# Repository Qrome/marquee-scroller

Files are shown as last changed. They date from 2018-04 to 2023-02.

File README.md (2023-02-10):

# Marquee Scroller (Clock, Weather, News, and More)

## NOTICE
The latest version of Marquee Scroller 3.01 works with **ESP8266 Core 3.0.2** -- if you are upgrading from Marquee Scroller 2.X version this may require you to enter in all your API Keys and settings.  Always meake sure you have coppied all your API keys somewhere before updating.  The ESP8266 Core 3.0.2 uses the newer FS (file system) that may require a fresh start on the configuration.
Make sure you update to the latest version of WifiManager library (link below).
* Removed Bitcoin features in 3.0

## Features include:
* Accurate Clock refresh off Internet Time Servers
* Local Weather and conditions (refreshed every 10 - 30 minutes)
* News Headlines from all the major sources
* Configured through Web Interface
* Display 3D print progress from your OctoPrint Server
* Option to display Pi-hole status and graph (each pixel accross is 10 minutes)
* Basic Authorization around Configuration web interface
* Support for OTA (loading firmware over WiFi)
* Update firmware through web interface
* Configurable scroll speed
* Configurable scrolling frequency
* Configurable number of LED panels
* Options of different types of Clock Displays (display seconds or temperature) -- only on 8 or more display panels
* Video: https://youtu.be/DsThufRpoiQ
* Build Video by Chris Riley: https://youtu.be/KqBiqJT9_lE

## Required Parts:
* Wemos D1 Mini: https://amzn.to/3tMl81U
* Dot Matrix Module: https://amzn.to/2HtnQlD  

Note: Using the links provided here help to support these types of projects. Thank you for the support.  

## Wiring for the Wemos D1 Mini to the Dot Matrix Display
CLK -> D5 (SCK)  
CS  -> D6  
DIN -> D7 (MOSI)  
VCC -> 5V+  
GND -> GND-  

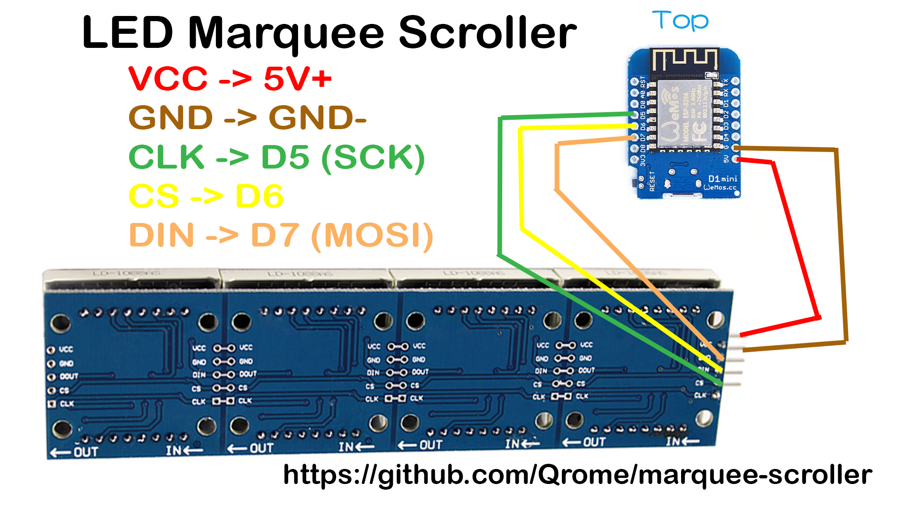
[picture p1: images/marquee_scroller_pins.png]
Marquee Scroller Wiring
  

## 3D Printed Case by David Payne:  
Original Single Panel version: https://www.thingiverse.com/thing:2867294  
Double Wide LED version: https://www.thingiverse.com/thing:2989552  

## Upgrading from version 2.5 or Higher
In version 2.6 and higher, the binary files that can be uploaded to your marque scrolling clock via the web interface.  From the main menu in the web interface select "Firmware Update" and follow the prompts.
* **marquee.ino.d1_mini_3.01.bin** - compiled for Wemos D1 Mini and standard 4x1 LED (default)
* **marquee.ino.d1_mini_wide_3.01.bin** - compiled for Wemos D1 Mini and double wide 8x1 LED display

## Compiling and Loading to Wemos D1
It is recommended to use Arduino IDE.  You will need to configure Arduino IDE to work with the Wemos board and USB port and installed the required USB drivers etc.  
* USB CH340G drivers:  https://sparks.gogo.co.nz/ch340.html
* Enter http://arduino.esp8266.com/stable/package_esp8266com_index.json into Additional Board Manager URLs field. You can add multiple URLs, separating them with commas.  This will add support for the Wemos D1 Mini to Arduino IDE.
* Open Boards Manager from Tools > Board menu and install esp8266 Core platform version Latest **3.0.2**
* Select Board:  "ESP8266 Boards (3.0.2)" --> "LOLIN(WEMOS) D1 R2 & mini"
* Set Flash Size: 4MB (FS:1MB OTA:~1019KB) -- **this project requires FS for saving and reading configuration settings.**
* Select the **Port** from the tools menu.  

## Loading Supporting Library Files in Arduino
Use the Arduino guide for details on how to installing and manage libraries https://www.arduino.cc/en/Guide/Libraries  
**Packages** -- the following packages and libraries are used (download and install):  
<WiFiManager.h> --> https://github.com/tzapu/WiFiManager (latest)  
<TimeLib.h> --> https://github.com/PaulStoffregen/Time  
<Adafruit_GFX.h> --> https://github.com/adafruit/Adafruit-GFX-Library  
<Max72xxPanel.h> --> https://github.com/markruys/arduino-Max72xxPanel  
<JsonStreamingParser.h> --> https://github.com/squix78/json-streaming-parser  

Note ArduinoJson (version 5.13.1) is now included as a library file in version 2.7 and later.

## Initial Configuration
Editing the **Settings.h** file is totally optional and not required.  All API Keys are now managed in the Web Interface. It is not required to edit the Settings.h file before loading and running the code.  
* Open Weather Map free API key: http://openweathermap.org/  -- this is used to get weather data and the latitude and longitude for the current time zone. Weather API key is required for correct time.
* TimeZoneDB free registration for API key: https://timezonedb.com/register -- this is used for setting the time and getting the correct time zone as well as managing time changes due to Day Light Savings time by regions.  This key is set and managed only through the web interface and added in version 2.10 of Marquee Scroller. TimeZoneDB key is required for correct time display.
* News API key (free): https://newsapi.org/ -- Optional if you want to get current news headlines.
* Your OctoPrint API Key -- optional if you use the OctoPrint status.
* Version 2.0 supports Chained 4x1 LED displays -- configure up to 16x1 in the Settings.h file.  

NOTE: The settings in the Settings.h are the default settings for the first loading. After loading you will manage changes to the settings via the Web Interface. If you want to change settings again in the settings.h, you will need to erase the file system on the Wemos or use the “Reset Settings” option in the Web Interface.  

## Web Interface
The Marquee Scroller uses the **WiFiManager** so when it can't find the last network it was connected to 
it will become a **AP Hotspot** -- connect to it with your phone and you can then enter your WiFi connection information.

After connected to your WiFi network it will display the IP addressed assigned to it and that can be 
used to open a browser to the Web Interface.  You will be able to manage your API Keys through the web interface.  
The default user / password for the configuration page is: admin / password  

The Clock will display the time of the City selected for the weather.  

<p align="center">
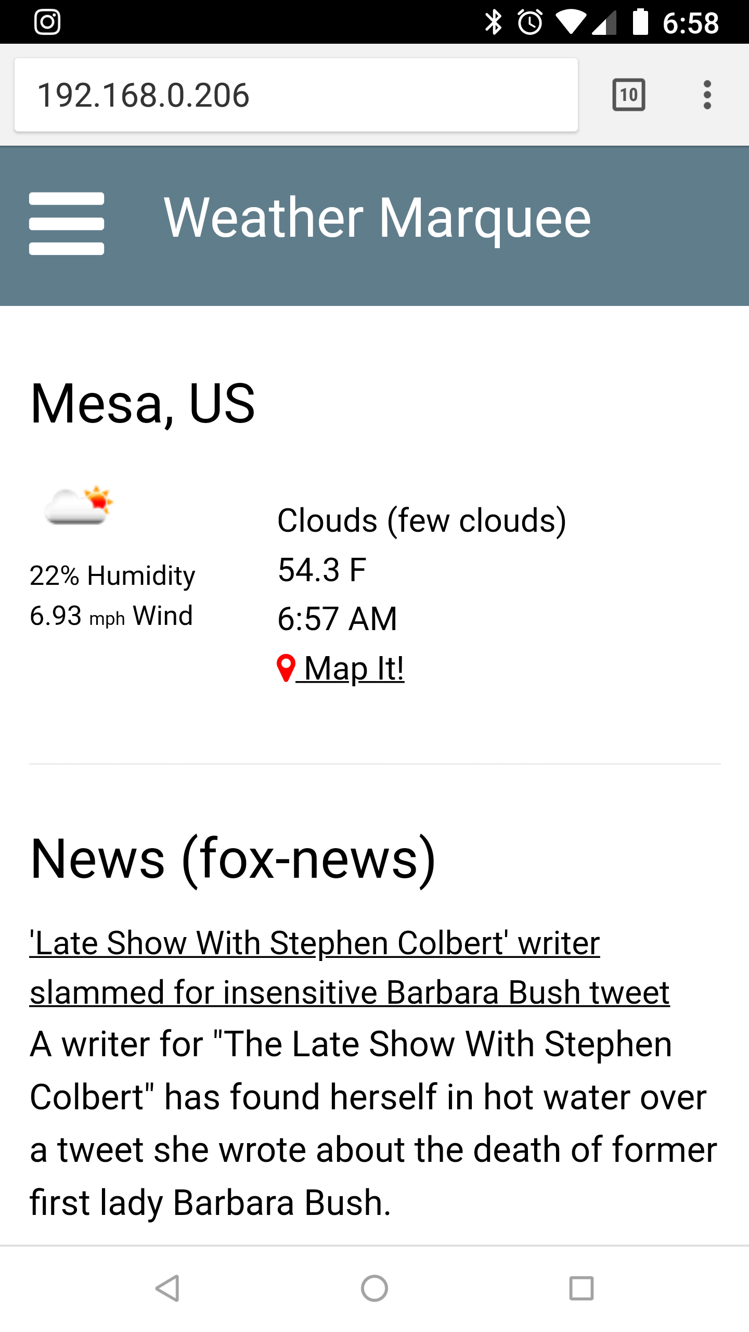
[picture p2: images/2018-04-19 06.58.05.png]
  
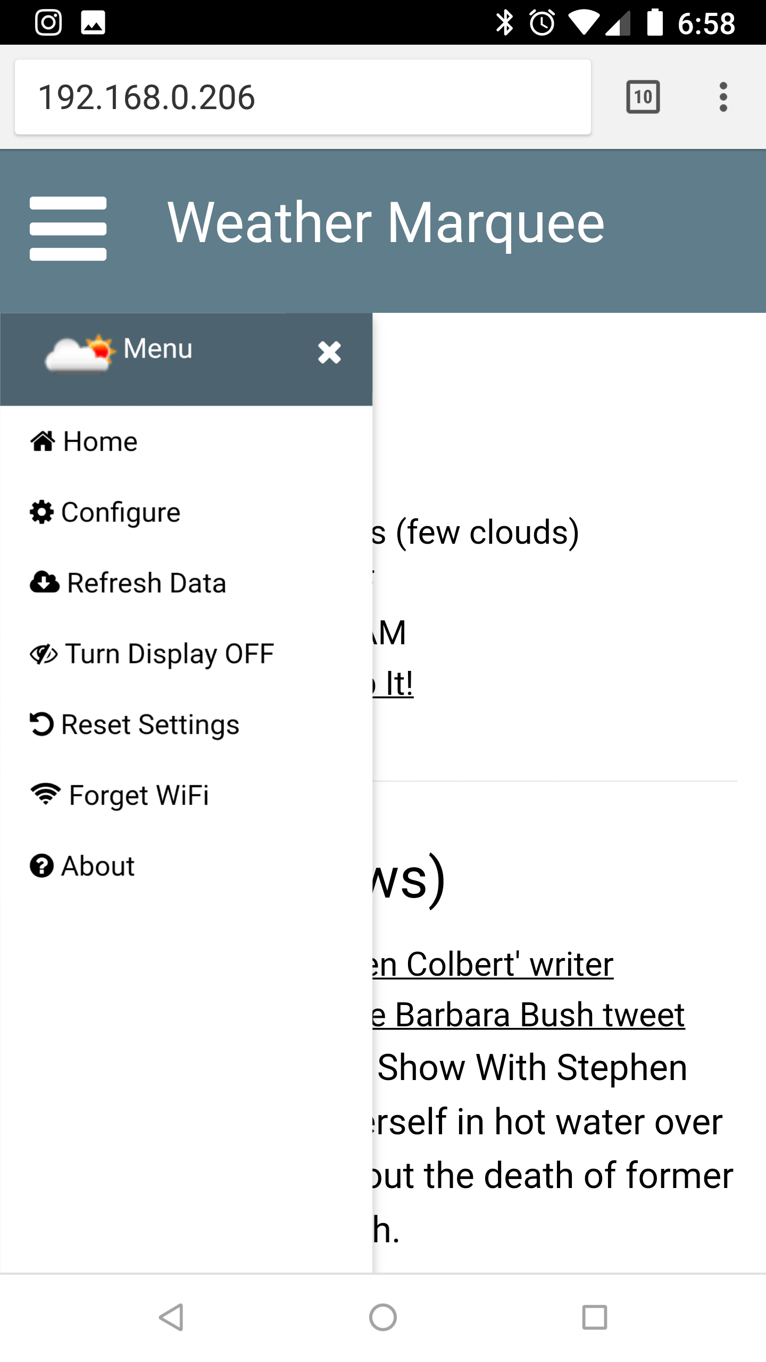
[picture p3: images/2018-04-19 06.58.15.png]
  
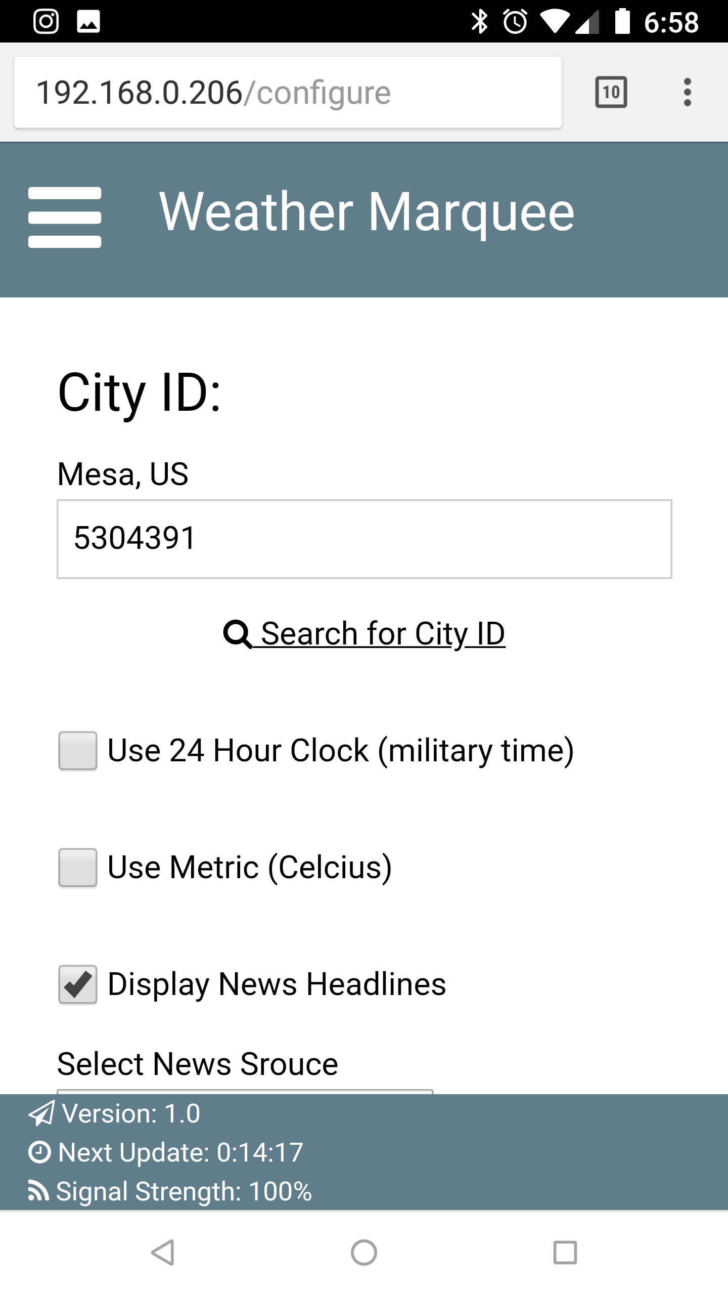
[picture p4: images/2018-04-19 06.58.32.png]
  
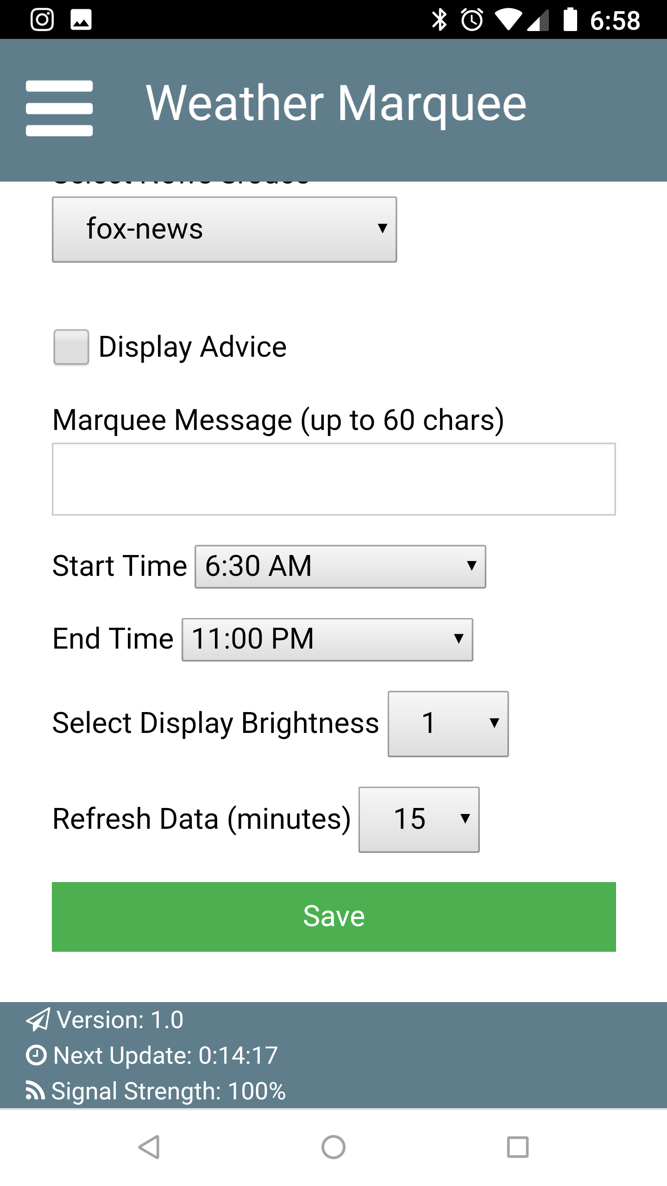
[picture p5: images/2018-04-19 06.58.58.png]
  
</p>

## Donation or Tip
Please do not feel obligated, but donations and tips are warmly welcomed.  I have added the donation button at the request of a few people that wanted to contribute and show appreciation.  Thank you, and enjoy the application and project.  



Or -- you can buy me something from my Amazon Wishlist: https://www.amazon.com/hz/wishlist/ls/GINC2PHRNEY3  

## Contributors
David Payne  
Nathan Glaus  
Daniel Eichhorn -- Author of the TimeClient class (in older versions)  
yanvigdev  
nashiko-s  
magnum129  

Contributing to this software is warmly welcomed. You can do this basically by forking from master, committing modifications and then making a pulling requests against the latest DEV branch to be reviewed (follow the links above for operating guide). Detailed comments are encouraged. Adding change log and your contact into file header is encouraged. Thanks for your contribution.

When considering making a code contribution, please keep in mind the following goals for the project:
* User should not be required to edit the Settings.h file to compile and run.  This means the feature should be simple enough to manage through the web interface.
* Changes should always support the recommended hardware (links above).

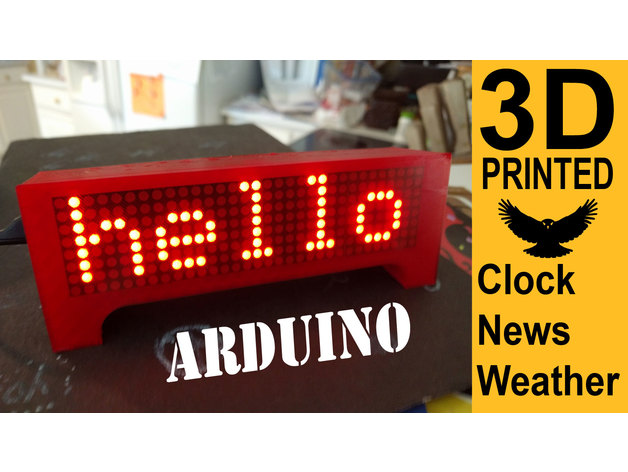
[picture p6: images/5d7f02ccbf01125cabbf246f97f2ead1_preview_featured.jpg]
Marquee Scroller
  
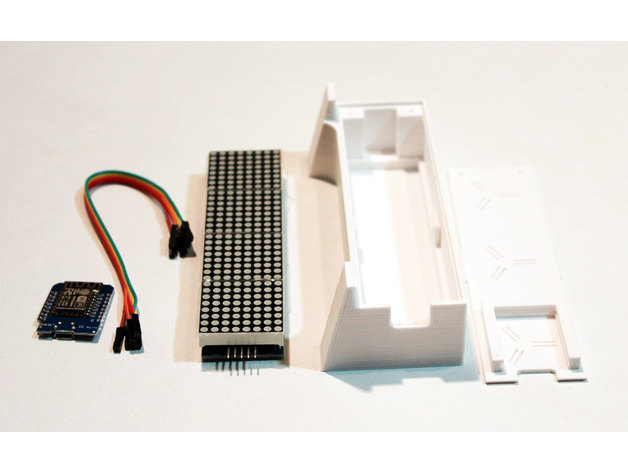
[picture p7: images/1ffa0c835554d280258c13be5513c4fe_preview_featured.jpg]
Marquee Parts


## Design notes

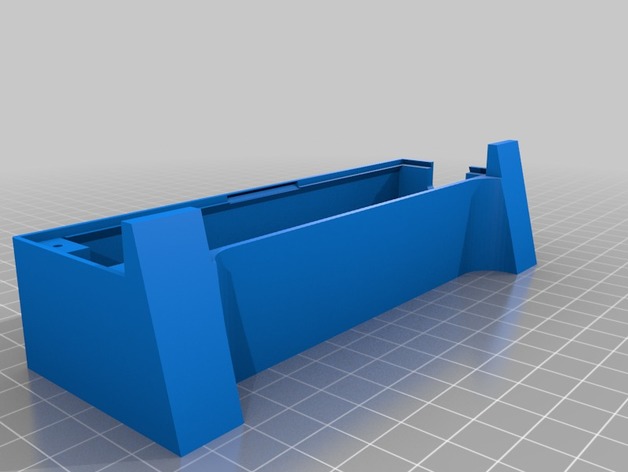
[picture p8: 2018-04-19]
images/5edbd35c7661400b3e7497d05f062c51_preview_featured.jpg

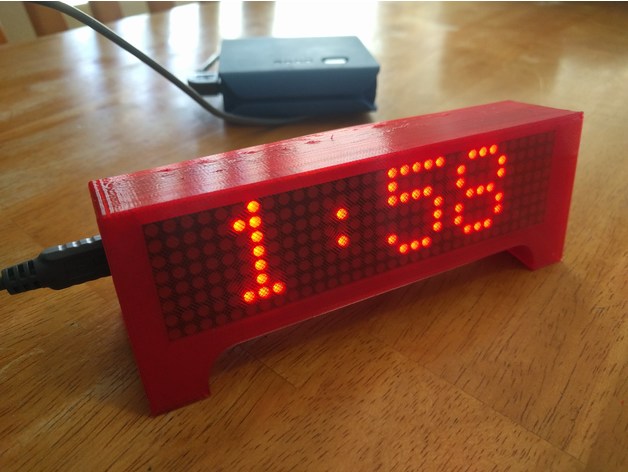
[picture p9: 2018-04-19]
images/3f594e3425ac3c804289af92a027742d_preview_featured.jpg

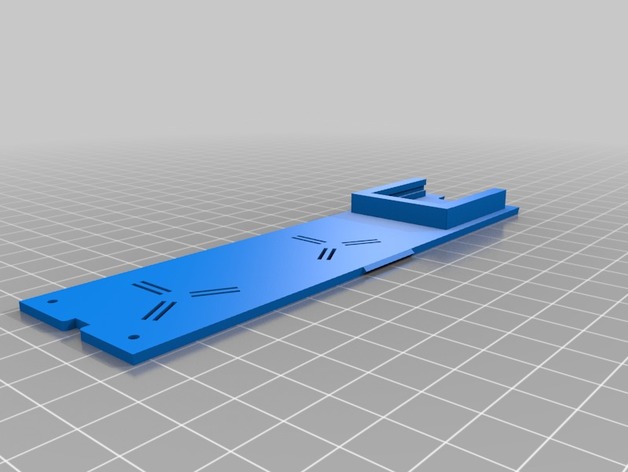
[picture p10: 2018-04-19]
images/e5a6cbe3afd816ad832b2e63c4659178_preview_featured.jpg

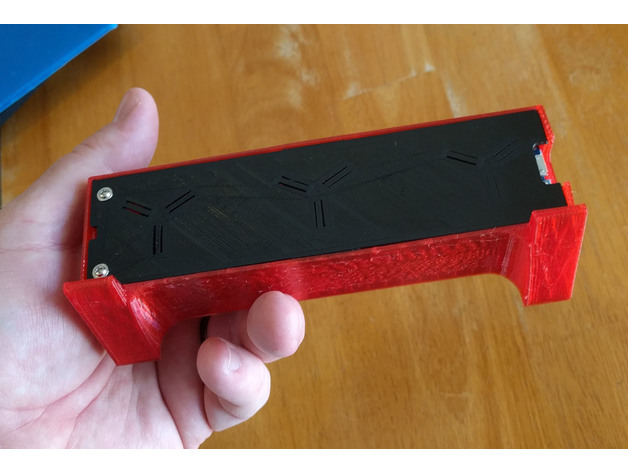
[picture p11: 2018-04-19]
images/b88dc7bd1fbfe809c30d6fec49e46fee_preview_featured.jpg

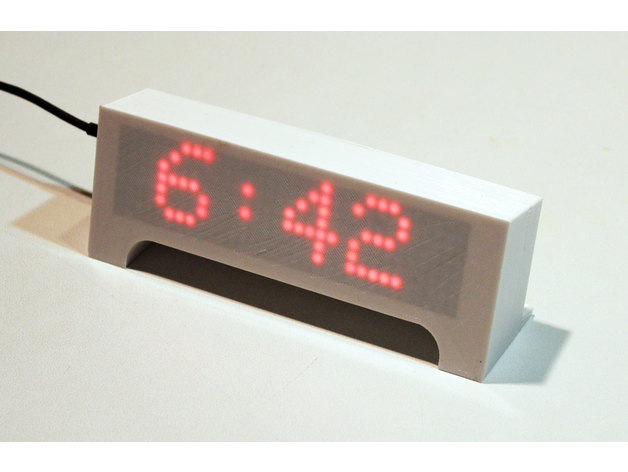
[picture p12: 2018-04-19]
images/51da51668716d4724db56edc0ee6d279_preview_featured.jpg

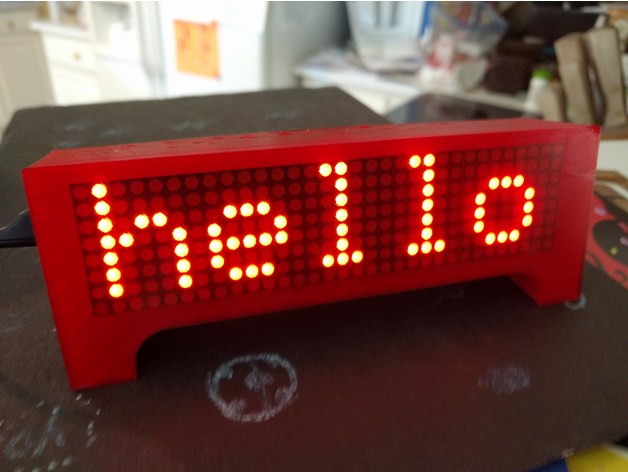
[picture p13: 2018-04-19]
images/87891f6c7e87ba8a31c5c7ec710eefff_preview_featured.jpg

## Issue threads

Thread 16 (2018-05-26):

Decimal places in temp and wind speed

fixyourlan, 2018-05-26:
Great case and device,  but my display is a little longer then the space in the case. I didn't buy the ones from Amazon you had the link too. I already had 4 of the quad displays from China sitting on my bench.  Another 2mm on the long side next to the white edge of the LED's the part that touches the thin display would work for my displays. The PCB the LED's mount to fits ok, its just the LED module is a little bigger I guess from other mfgs.

Can you mod the code to make the temp read just 78F instead of 78.7F and the wind speed 9 instead of 9.77.  No one can tell the difference with fractions of a degree and speed! I would make it easier to read as it scrolls by. I don't know why WU publishes it that way, but if you could fix it it would be a lot better!

Qrome, 2018-05-28:
This is actually something I had considered a while back.  I added additional methods to the WU client to get the rounded values.   I have updated the latest release of 1.8 to round to the nearest whole values for Temp and Wind.

Closed 2018-05-28.

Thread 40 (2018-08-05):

Blank pages served after fully configuring.

westerncanada, 2018-08-05:
Good afternoon,

Up until the point where I added all of the API keys to the web interface, I was able to load the main page, and make changes, however now that I've added the news and weather API keys to the web interface, I am no longer able to load the page.

Running some diagnostics with Curl show:
`curl: (56) Illegal or missing hexadecimal sequence in chunked-encoding`

But other times nothing loads.
The LED display is working, loading the time, weather and news.
I'm running a version pulled this morning, on a Node MCU esp8266

I tried to add the settings I want to change (news to cbc-news) to the config.h however I think that is ignored for the web stored values after setup.

Very cool project, cannot wait to see if MQTT will ever be added in.

Thank you

Qrome, 2018-08-05:
As mentioned in the Readme.md -- changing the Settings.h does not do anything after the initial load.  Those are defaults for the first time loading or when you do a full reset.

Can  you please share what version you have loaded?   The current version is 2.2.

westerncanada, 2018-08-05:
Yeah, I was only using the Settings.h because the web interface would not load for me, so for now I'm making changes to the Settings.h, and calling the /systemreset URL to make changes, its not pretty but does the job.

Confirming this is on version 2.2

I'll download it again, and wipe the NodeMCU to see if it does anything different a bit later.

Qrome, 2018-08-05:
This latest version of 2.2 had many changes to resolve the memory issues that typically cause the blank pages to start showing up.   I am running the Wemos D1 Mini (quite a few of them) and the latest version 2.2 seems to have resolved the partial page loading issue.  I am wondering if the NodeMCU you have has some different memory limitations.   Unfortunately the web page serving is String intensive -- and there is a struggle to try and keep the code workable at the same time.

Currently I am not having the blank or partial page loading for the Wemos D1 Mini (EPS8266).   I plan on ordering a NodeMCU anyway and try and have a look at it.

westerncanada, 2018-08-05:
That's a good point, I've got a couple of Wemos D1 Mini Pros here, I might give one a go.  Saves from having to hack up the STL to fit the longer board for the (very nice) case you designed.

The NodeMCU's I'm using are v2 because they fit on breadboard, unlike the v3 that is way too wide and doesn't fit on breadboard at all.

This is what they [look like](https://www.amazon.ca/Kuman-Internet-Development-wireless-controller/dp/B06VV39XD8) they can be had much cheaper from aliexpress if you're good with waiting for shipping.

Sterft, 2019-01-03:
I have the same issue, though it disappears when I set the news source to not be Reuters strangely enough. After that the pages load just fine. And I think it fixes another issue I had, where it would be stuck in a weather parsing error after some time.
Using [this board](https://www.aliexpress.com/item/ESP-12E-WeMos-D1-WiFi-uno-based-ESP8266-shield-for-arduino-Compatible/32821901911.html
)

Changed the news source by going to this:
http://192.168.x.x/savenews?displaynews=on&newsApiKey=xxx&newssource=time

Qrome, 2019-01-04:
If you run into the memory issues, just reboot it for now.

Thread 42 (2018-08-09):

Some changes I made in the code

hutje, 2018-08-09:
All changes I made are hardcoded for me.

- I have made a change in the newsapi. This allows me to add country instead of sources, so I can see the news of my country.
- I have made a change in the sync weather function. Now I am able to still see the time while updating. Maybe I will add a dot in every corner while syncing to see how far the syncing process is.
- I have added lang=%language% inside the string of the openweathermap api to allow me to get the description in my own language.  (See: https://openweathermap.org/current at Multilingual support)
- Also changed the Humidity and Windspeed to my own language.

Thanks for this awesome arduino program!

Qrome, 2018-08-10:
Do you want to contribute the suggested changes via a Pull Request?

hutje, 2018-08-16:
Hey Qrome,

Would it be possible to attach the fusion360 file with the Thingiverse design? I really would like to edit this model to make it usable for 6 displays and also want to build a 4cm speaker+mp3 module inside to make it act as an alarm clock.

Thanks!

Qrome, 2018-09-04:
I designed it in TinkerCad and it is only available as an STL from there.  Sorry.

drogica, 2018-09-07:
[ledmatrix v7.zip](https://github.com/Qrome/marquee-scroller/files/2362550/ledmatrix.v7.zip)

pl4y3r2nd, 2018-12-02:
is it technically possible to get German or polish letters on led screen?

Qrome, 2018-12-02:
@drogica -- nice looking box!

Qrome, 2018-12-02:
@pl4y3r2nd -- It was frustrating to learn that the fonts used in the marquee scroller does not have a full international character set.   If someone wants to try and implement those, that would be great.   As for now, the full international letter set is not supported.

Qrome, 2018-12-21:
@MachmaHinne thanks!   The project uses the Max72xxPanel and that in turn uses the Adafruit_GFX library -- the fonts belong to the Adafruit_GFX.   I have not spent much time looking at it, however I have generated my own fonts for another project but not for the LED matrix.
https://github.com/markruys/arduino-Max72xxPanel

MachmaHinne, 2018-12-21:
Ok. I think there is hope for a solution for this problem. The Adafruit GFX lib contains only 7-bit fonts. But I found a tool that can generate also 8-bit fonts. I´ll stick on this.
https://blog.squix.org/2016/10/font-creator-now-creates-adafruit-gfx-fonts.html

At the moment I have a problem with a bunch of 8x64 Modules I ordered at banggood.com, because the order of the 4 panels is reversed. #1 is on the right, #4 is on the left. Does anyone have heard about that problem? Any hints?

MachmaHinne, 2018-12-21:
After reading arduino-Max72xxPanel-master, I´m not so confident any more, because this lib has to be changed for that. And the development of it seems to be dead.

For the problem with my modules I had to change matrix.setRotation(i, 3); to matrix.setRotation(i, 1);
But now I have to rotate the whole module and change the pins from one side to the other :(

Qrome, 2018-12-21:
I did a PR (change request) a while back to the arduino-Max72xxPanel-master -- if needed we could always create a branch of it to modify and include it as part of the marquee code.

As for the LED modules you have, I know there are some out there assembled differently than the ones I linked to.    Someone else had the same issue, the where able to do it through rotation only.

costascontis, 2019-01-28:
what should i change in the code so i can view news for my country (Greece) ?

Qrome, 2019-01-28:
@costascontis -- the quick and easy way would be to edit line 45 of theNewsApiClient.cpp file where it defines the URL that requests the news.

You can find samples here on how you might change it:  https://newsapi.org/docs/endpoints/top-headlines

phgsbr, 2019-03-04:
How can i get this changes? It would be perfect for me. I live in Brazil and i would like to translate the Weather infos to Portuguese and use a brazillian news source too.

phgsbr, 2019-03-10:
> How can i get this changes? It would be perfect for me. I live in Brazil and i would like to translate the Weather infos to Portuguese and use a brazillian news source too.

Anyone please?

Qrome, 2019-03-10:
The weather text comes from the weather service and would not be translated in the code here.    There are only a few words that are in the code -- you can find them and change them as needed.

The fonts supported by the marque do not include special characters as mentioned above.

phgsbr, 2019-03-17:
I tried to change the news source to globo ir googlenews-br (two news source from Brazil) in the code. But, after upload, the news source stills on BBC (currently before the change). How can i fix this?

Qrome, 2019-03-17:
You need to add it to the options in the ino file.  Also once it is loaded you have to use the web interface to change settings.

sjef1979, 2019-05-07:
@costascontis
How did you get this to work?

finnie2006, 2021-12-10:
Can the stuff from this issue get added to the project?
@Qrome

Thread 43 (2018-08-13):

Weather Data Parsing failed!

2A3, 2018-08-13:
I'm getting an error "Weather Data Parsing failed!" in both a singe wide and double wide setup.
Refreshing the data thru the web page doesn't fix the issue, but hitting the reset button does.

Any ideas of what could be the cause?

Qrome, 2018-08-14:
What city ID are you using?   Could there be something in the response for your selected City that might be causing the parsing to fail?   Can you share the version you are using as well as the City ID.
Thanks.

LotusMA, 2018-08-14:
I got this same error with city code 4952005. Happens after about 3 hours. Thought it was something to do with my edits to the code but happens with standard version 2,2

2A3, 2018-08-14:
Hillsborough County, US City ID:  5087463
I'm using Version 2.3
I've built both the 4 (single) and 8 (double) and it happens with both.  If I reboot both it will happen again at different times.
Changing display options (eg, humidity, windspeed, date etc) doesn't prevent the problem.

Many thanks!

- Gary

Qrome, 2018-08-15:
The parsing error means that the response from the openweather.org was not a good response that the ArduinoJson could read through.   It makes me wonder if occasionally you are getting a bad response.

Qrome, 2018-08-15:
Ok, I have made some changes to the 2.3 dev branch.  Apparently it would loop and display the error message.   This was originally done if a user had configured incorrect weather api-key or city ID so it would not continue to hit the weather service.   This update should try again on the next normal data refresh (usually 15 minutes).   I have also updated it to show other types of weather errors like 404 on CityID not found and stuff like that.  Please try the latest 2.3 dev branch.

2A3, 2018-08-16:
I installed the updated files tonight on both 4 and 8 segment units.  They've been running for about 4 hours so far and seem solid.  I'll see how they do.  Thanks again for all of the help.

Qrome, 2018-08-16:
Sounds good.  Let me know how it goes.

Qrome, 2018-08-17:
Thanks for the update and for testing it out.  Occasionally there might be a bad response from the weather service but with this update it won't stay in the error loop and can get out of it and try again.

Qrome, 2018-08-24:
Released this in 2.3.

pkarza, 2018-12-01:
This is giving me a problem on 2.5 - city code 6119109

I can reboot for forget wifi - but it happens after a few hours and won't update.

Qrome, 2018-12-01:
Philip, your issue doesn't have anything to do with the original issue posted here.   Is it possible your device is being disconnected from your router?   Can you pull up the web interface when it gets a weather parsing failed?   This is usually an indication of connectivity.   If you plug it in to your computer and use the Serial Monitor and capture what is happening, that would be helpful.

pkarza, 2018-12-01:
I have moved the clock to be right by the wifi - and it has a powerful output - the web interface still works when it gives the parsing error. - that is strange.  That is where I use the forget wifi option and it works again.

If I turn off the weather completely, the news will work and it does not fail - and if I have a ocdtoprint job to monitor, it is also fine. Just the weather!

Neeraj-Ch, 2018-12-01:
I have the same problem. Also even clock is connected to internet & Everything ok.
1 . Many times Weather data parsing error.
2 . Web interface is not as it should be. Its very unusual . In Simple HTML only

Qrome, 2018-12-01:
Again, the original issue was that it would not attempt to get the weather data after the first error, that was fixed in version 2.3.

Now if you can run the serial monitor to capture the error response from the weather service that would give you an indication why your clock can't reach the weather service.   The parsing error occurs when it can't reach the weather service or if the weather service returns an error.   There is nothing I can do about the weather service, router, or connectivity.

If you can run the serial monitor often the weather service will respond with what the issue is:  it could be the api key is over used or rejected.

When it happens again, go to the web interface and click the "Refresh Data" -- this forces the clock to pull all fresh data from the weather, news, etc.   Check the Serial Monitor when you do this and you can see the responses for the services.

pkarza, 2018-12-02:
Ok - I'll try a different API key - and I'm sure how to use the serial monitor... It has to be something simple.

pkarza, 2018-12-03:
Well - here is a copy - the news works - but the weather doesn't - I'll post the one that and the one that did not...

19:31:28.926 -> Getting Weather Data
19:31:28.926 -> GET /data/2.5/group?id=6119109&units=metric&cnt=1&APPID=8e6b124d9c516ff1938fa8e87fbe8490 HTTP/1.1
Waiting for data
19:31:29.114 -> Response Header: HTTP/1.1 200 OK
19:31:29.114 -> Weather Data Parsing failed!
Updating Time...
.
19:31:35.582 -> 01:31:32
19:31:35.582 -> 1:31:32
19:31:35.582 -> 5492
Getting News Data for reuters
19:31:40.598 -> Getting News Data
19:31:40.598 -> http://newsapi.org/v2/top-headlines?sources=reuters&apiK (NEWS WORKS)

------------------------------------------ Last working one.......
19:16:22.694 -> Getting Weather Data
19:16:22.694 -> GET /data/2.5/group?id=6119109&units=metric&cnt=1&APPID=8e6b124d9c516ff1938fa8e87fbe8490 HTTP/1.1
Waiting for data
19:16:22.834 -> Response Header: HTTP/1.1 200 OK
19:16:22.834 -> lat: 50.45
19:16:22.834 -> lon: -104.62
19:16:22.834 -> dt: 1543799780
19:16:22.834 -> city: Regina
19:16:22.834 -> country: CA
19:16:22.881 -> temp: -6
19:16:22.881 -> humidity: 92
19:16:22.881 -> condition: Clouds
19:16:22.881 -> wind: 3.1
19:16:22.881 -> weatherId: 804
19:16:22.881 -> description: overcast clouds
19:16:22.881 -> icon: 04n
19:16:22.881 ->
19:16:22.881 -> Updating Time...
.
19:16:23.912 -> 01:16:20
19:16:23.912 -> 1:16:20
19:16:23.912 -> 4580
Getting News Data for reuters
(news works)

pkarza, 2018-12-03:
and a follow up - I tried to refresh data - and here this is...  weird...
-----------------------------------------------------------------------------
9:35:57.183 -> Getting Weather Data
19:35:57.183 -> GET /data/2.5/group?id=6119109&units=metric&cnt=1&APPID=8e6b124d9c516ff1938fa8e87fbe8490 HTTP/1.1
Waiting for data
19:35:57.417 -> Response Header: HTTP/1.1 200 OK
19:35:57.417 -> Weather Data Parsing failed!

19:36:02.245 -> Getting Weather Data
19:36:02.245 -> GET /data/2.5/group?id=6119109&units=metric&cnt=1&APPID=8e6b124d9c516ff1938fa8e87fbe8490 HTTP/1.1

19:36:05.011 -> Panic C:\Users\Phil Karza\AppData\Local\Arduino15\packages\esp8266\hardware\esp8266\2.4.1\cores\esp8266\core_esp8266_main.cpp:130 loop_task
19:36:05.058 ->
19:36:05.058 -> ctx: sys
19:36:05.058 -> sp: 3ffffdd0 end: 3fffffb0 offset: 01b0
19:36:05.058 ->
19:36:05.058 -> >>>stack>>>
19:36:05.058 -> 3fffff80:  4024f972 3fffdab0 00000000 3fff3fa0
19:36:05.058 -> 3fffff90:  00000000 3fffdad0 3fff3f98 4021fac1
19:36:05.058 -> 3fffffa0:  40000f49 3fffdab0 3fffdab0 40000f49
19:36:05.058 -> <<<stack<<<
19:36:05.058 ->
19:36:05.058 ->  ets Jan  8 2013,rst cause:2, boot mode:(3,0)
19:36:05.058 ->
19:36:05.058 -> load 0x4010f000, len 1384, room 16
19:36:05.058 -> tail 8
19:36:05.058 -> chksum 0x2d
19:36:05.058 -> csum 0x2d
19:36:05.058 -> v614f7c32
19:36:05.058 -> ~ld
sy⸮|⸮⸮⸮n  c ⸮gl⸮|⸮⸮g|p
l⸮|   o⸮⸮⸮ ⸮ 㓃
 b ⸮g`{l
APIKEY: 8e6b124d9c516ff1938fa8e87fbe8490
19:36:05.198 -> CityID: 6119109
19:36:05.198 -> marqueeMessage=
19:36:05.198 -> newsSource=reuters
19:36:05.198 -> timeDisplayTurnsOn=06:30
19:36:05.198 -> timeDisplayTurnsOff=23:00
19:36:05.198 -> displayIntensity=1
19:36:05.198 -> displayScrollSpeed=25
19:36:05.198 -> NEWS_ENABLED=1
19:36:05.198 -> NEWS_API_KEY: ffaccabf65ae491a83551c0f787a82f1
19:36:05.198 -> IS_24HOUR=0
19:36:05.198 -> IS_DST=0
19:36:05.198 -> Wide_Clock_Style=1
19:36:05.198 -> IS_METRIC=1
19:36:05.198 -> minutesBetweenDataRefresh=15
19:36:05.198 -> minutesBetweenScrolling=1
19:36:05.198 -> OCTOPRINT_ENABLED=1
19:36:05.198 -> OctoPrintApiKey=BF11F278B2374200A1BB1495F80CA706
19:36:05.198 -> OctoPrintServer=172.16.1.102
19:36:05.198 -> OctoPrintPort=80
19:36:05.198 -> OctoAuthUser=
19:36:05.198 -> OctoAuthPass=
19:36:05.198 -> www_username=admin
19:36:05.198 -> www_password=password
19:36:05.245 -> IS_BASIC_AUTH=1
19:36:05.245 -> BitcoinCurrencyCode=NONE
19:36:05.245 -> SHOW_CITY=1
19:36:05.245 -> SHOW_CONDITION=0
19:36:05.245 -> SHOW_HUMIDITY=0
19:36:05.245 -> SHOW_WIND=0
19:36:05.245 -> SHOW_DATE=1
19:36:05.245 -> Number os LED Displays: 4
19:36:05.245 -> matrix created
*WM:
19:36:11.339 -> *WM: AutoConnect
19:36:11.339 -> *WM: Connecting as wifi client...
19:36:11.339 -> *WM: Already connected. Bailing out.
19:36:11.339 -> *WM: IP Address:
19:36:11.339 -> *WM: 172.16.1.80
19:36:11.339 -> Signal Strength (RSSI): 30%
19:36:11.339 -> Server started
19:36:11.339 -> Use this URL : http://172.16.1.80:80/

19:36:11.620 -> Getting Weather Data
19:36:11.620 -> GET /data/2.5/group?id=6119109&units=metric&cnt=1&APPID=8e6b124d9c516ff1938fa8e87fbe8490 HTTP/1.1
Waiting for data
19:36:11.807 -> Response Header: HTTP/1.1 200 OK
19:36:11.807 -> lat: 50.45
19:36:11.807 -> lon: -104.62
19:36:11.807 -> dt: 1543800969
19:36:11.807 -> city: Regina
19:36:11.807 -> country: CA
19:36:11.807 -> temp: -6
19:36:11.807 -> humidity: 92
19:36:11.807 -> condition: Clouds
19:36:11.807 -> wind: 4.6
19:36:11.807 -> weatherId: 804
19:36:11.854 -> description: overcast clouds
19:36:11.854 -> icon: 04n
19:36:11.854 ->
19:36:11.854 -> Updating Time...
.

pkarza, 2018-12-05:
is there any way to load this without the weather - and only have news??

Closed 2018-08-24.

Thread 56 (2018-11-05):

Issues with Arduino Json library

dino340, 2018-11-05:
Attempting to compile on Arduino IDE 1.8.7 yields this error message:

```Arduino: 1.8.7 (Windows Store 1.8.15.0) (Windows 10), Board: "WeMos D1 R1, 80 MHz, Flash, 4M (1M SPIFFS), v2 Lower Memory, Disabled, None, Only Sketch, 921600"

sketch\GeoNamesClient.cpp: In member function 'float GeoNamesClient::getTimeOffset()':

GeoNamesClient.cpp:80:3: error: 'DynamicJsonBuffer' was not declared in this scope

   DynamicJsonBuffer json_buf;

   ^

GeoNamesClient.cpp:80:21: error: expected ';' before 'json_buf'

   DynamicJsonBuffer json_buf;

                     ^

GeoNamesClient.cpp:81:22: error: 'json_buf' was not declared in this scope

   JsonObject& root = json_buf.parseObject(jsonArray);

                      ^

sketch\OctoPrintClient.cpp: In member function 'void OctoPrintClient::getPrinterJobResults()':

OctoPrintClient.cpp:114:3: error: 'DynamicJsonBuffer' was not declared in this scope

   DynamicJsonBuffer jsonBuffer(bufferSize);

   ^

OctoPrintClient.cpp:114:21: error: expected ';' before 'jsonBuffer'

   DynamicJsonBuffer jsonBuffer(bufferSize);

                     ^

OctoPrintClient.cpp:117:22: error: 'jsonBuffer' was not declared in this scope

   JsonObject& root = jsonBuffer.parseObject(printClient);

                      ^

OctoPrintClient.cpp:118:13: error: 'class ArduinoJson650_0_0::JsonObject' has no member named 'success'

   if (!root.success()) {

             ^

sketch\OpenWeatherMapClient.cpp: In member function 'void OpenWeatherMapClient::updateWeather()':

OpenWeatherMapClient.cpp:81:3: error: 'DynamicJsonBuffer' was not declared in this scope

   DynamicJsonBuffer jsonBuffer(bufferSize);

   ^

OpenWeatherMapClient.cpp:81:21: error: expected ';' before 'jsonBuffer'

   DynamicJsonBuffer jsonBuffer(bufferSize);

                     ^

OpenWeatherMapClient.cpp:84:22: error: 'jsonBuffer' was not declared in this scope

   JsonObject& root = jsonBuffer.parseObject(weatherClient);

                      ^

OpenWeatherMapClient.cpp:85:13: error: 'class ArduinoJson650_0_0::JsonObject' has no member named 'success'

   if (!root.success()) {

             ^

OpenWeatherMapClient.cpp:93:12: error: 'class ArduinoJson650_0_0::JsonObject' has no member named 'measureLength'

   if (root.measureLength() <= 150) {

            ^

OpenWeatherMapClient.cpp:94:86: error: 'class ArduinoJson650_0_0::JsonObject' has no member named 'measureLength'

     Serial.println("Error Does not look like we got the data.  Size: " + String(root.measureLength()));

                                                                                      ^

sketch\BitcoinApiClient.cpp: In member function 'void BitcoinApiClient::updateBitcoinData(String)':

BitcoinApiClient.cpp:92:3: error: 'DynamicJsonBuffer' was not declared in this scope

   DynamicJsonBuffer json_buf;

   ^

BitcoinApiClient.cpp:92:21: error: expected ';' before 'json_buf'

   DynamicJsonBuffer json_buf;

                     ^

BitcoinApiClient.cpp:93:22: error: 'json_buf' was not declared in this scope

   JsonObject& root = json_buf.parseObject(jsonArray);

                      ^

BitcoinApiClient.cpp:95:13: error: 'class ArduinoJson650_0_0::JsonObject' has no member named 'success'

   if (!root.success()) {

             ^

exit status 1
'DynamicJsonBuffer' was not declared in this scope

This report would have more information with
"Show verbose output during compilation"
option enabled in File -> Preferences.

```

Qrome, 2018-11-05:
This is addressed in the README.md file.  You are using a beta version of ArduinoJson -- you need to use the 5.13.X version.

dino340, 2018-11-05:
Thank you for the quick response, this was indeed the case, I didn't realize I was running the beta version of the ArduinoJson, reverted and it compiled :D

Closed 2018-11-05.

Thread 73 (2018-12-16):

Version 2.6 causes all or most of matrix illuminated and hangs

dino340, 2018-12-16:
Updated existing hardware (worked fine on 2.4) and flashed new hardware (Wavgat D1 Mini), Both clocks either display all LEDs lit or most lit (nonuniform unchanging unlit pixels). Cannot seem to find either clock or connect via wifi.

Flashed with Arduino IDE 1.8.8
LOLIN(WEMOS) D1 R2 & mini, 80MHz CPU speed, Flash size 4M (no SPIFFS) v2 lower memory, All Flash Contents (after trying other options)

Qrome, 2018-12-16:
Honestly, it sounds like you have hardware issues.   there is nothing in the code that changed the control of the LEDs -- check the pins on your LED strips that they are all connected.

Try loading the clock from the compiled binary included in the 2.6 released.

I am using Arduino 1.8.5 with ESP8266 core 2.4.2 -- there have been  no changes in the LED operation.  In fact the memory usage is lower in 2.6 as it no longer includes Advice Slip.   I am wondering if you have issues with a newer library or something around Arduino 1.8.8.

Also, why does your say (no SPIFFS)?

Qrome, 2018-12-16:
I just tested with Arduino 1.8.8 -- mine defualted to (1M SPIFFS) and worked just fine.  So it isn't 1.8.8 -- I have a feeling you loaded the new beta version of ESP8266 Core of 2.5.X -- even with that the version 2.6 should work as that has been tested as well.

I am sure it is related to the (no SPIFFS) -- SPIFFS is required for the settings file to save and load settings.  this would cause it to hang on boot.  The odd thing is, I don't even have the option to select (no SPIFFS).

Qrome, 2018-12-16:
Ok, I have now loaded the newer Beta ESP8266 core 2.5.0 and it did default my settings to (no SPIFFS) in Arduino 1.8.8.   I selected (1M SPIFFS) and loaded it and it is working just fine.   I suspect that was your issue since it was hanging trying to load the settings on boot.   Please confirm and I will close the issue.

dino340, 2018-12-17:
My original clock is indeed working fine after selecting 1M SPIFFS, the issues with the 2nd board were caused by me reversing the wires to pins 5 and 7 and after rectifying that it is also working as well.

Thank you Qrome for your patience, the Arduino IDE constantly telling me to update libraries to beta versions seems to have caused me no end of issues with your clock code, as a suggestion could you please list which versions of the libraries to use? Though that will be less of an issue now that I can upload binaries through the web interface.

dino340, 2018-12-17:
One other small tangential issue, your released code is configured for 8x1 matrixes instead of the default 4x1, caused a little bit of confusion until I realized this and rectified it.

Closed 2018-12-17.

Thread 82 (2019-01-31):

Text becomes unviewable after restart

ben-barnard, 2019-01-31:
Full disclosure - I'm using (instead of the Wemos,) LoLin nodemcu v3, using all the same pins as in the README, and it works! However, if I shut down or restart the device, it appears that it is working (web interface still fine), but it looks like the bottom of the text is only showing up on the very top row of LEDs. The only way to resolve it is to reset settings, power down, and push the reset button after powering up.

fixyourlan, 2019-02-02:
Try different board settings in ardunio!

terrag42, 2019-02-04:
I had a similar issue, and thought it was a loose connection. Nope, it was just the cheap LED display that I got. To work around the issue, I just removed the USB power cable and put it back in a few times until the entire display lit up.
Hope that helps.

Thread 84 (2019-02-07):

LED Panels displaying incorrectly

cknieriem, 2019-02-07:
I purchased what I thought were 2 batches with the same SKU LED panels from Banggood.  One set works fine but the other batch initially displays "hello" backwards and misformed.  The items are

Geekcreit® MAX7219 Dot Matrix Module 4-in-1 Display For Arduino

Any ideas.  Maybe a different driver?
--

sorriso93, 2019-02-07:
I had the same problem. Try to modify setrotation for the panel inverted. For example I have a mixed configuration: first three panels with rotation 1 and 1 panel with rotation 3...

Qrome, 2019-02-07:
There are other brands than the one linked to in the readme file, however they work.   Some are assembled differently with different orientations.   You can adjust the orientation easy in the new 2.7 release branch.

https://github.com/Qrome/marquee-scroller/tree/2.7

Look for ledRotation in the Settings.h

cknieriem, 2019-02-07:
Thank you.  Rotation back to zero fixed the problem with this batch of panels.

Qrome, 2019-02-07:
Very cool.

Qrome, 2019-02-19:
The latest version release allows you to change orientation in the Settings.h file.   Thanks. guys.

Closed 2019-02-19.

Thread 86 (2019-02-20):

time display and info rotation and update

Franzsupersport, 2019-02-20:
Hi,
I made the marquee scroller and the printer monitor in both sizes 0,96 inches and 1,3 inches screen, evrything works fine when i turn it on, but it doesn't display the time and doesn't update the printing process.
If i disconnect power and start it again the printing processs appear updated, but remain in same status after (for example if i turn it on and printing is 60% it will remain 60% unless i reconnect the power).
For the marquee once i turn it on, it shows the weather info correctly, but then shows 2 lines that i guess should be the time (but it doesn't shows the time) and it stays like that forever..
I followed the pin connection strictly and upload the arduino file without problems.

Qrome, 2019-02-20:
Have you looked over at my other project [Printer Monitor](https://github.com/Qrome/printer-monitor)?  That project shows the print status as well as the clock -- just does not do the News.   Someone did a PR where they added the news to that project but I never merged it to the main code base.   It would be easier to add the News to that project than to convert this one to the OLED displays.

Honestly, I don't know if I could help you without seeing the code.

Franzsupersport, 2019-02-20:
Yes, actually i followed both video of Chris Riley on you tube and decided to make both.
of course i followed separately the project since connections and files are different, just i get the same problem on both.
The time doesn't appear, remain only 2 lines -- and stays like that. also as mentioned before, it update the info like weather on marquee and printing status on printer monitor only once when power on, and then never change till you disconnect power and power on again, like if it cannot connect anymore to get updates from the network. i don't know if the problem may be my network of the fact that i actually live in China and here internet is quite restricted..

Qrome, 2019-02-20:
You may need to change the time client as it uses google -- this could be the problem.  I think I have heard others mention problems running it in China.

Franzsupersport, 2019-02-20:
OH, yes it could be the problem, may i ask you how to do it? i don't have much experience with arduino, i just started about 2 months ago and still figuring out how to do everything.. thanks

Qrome, 2019-02-20:
Edit line 44 on the TimeClient.cpp file -- that is where the host name is for getting the time.   Try something else that would work in China.

Franzsupersport, 2019-02-22:
HI again,
i've searched for NTP servers in asia, i managed to find some, but i tried to do as you said and it still doesn't work. I think i'm missing something..

 // This will send the request to the server
  client.print(String("GET / HTTP/1.1\r\n") +
               String("Host: 1.cn.pool.ntp.org\r\n") +
               String("Connection: close\r\n\r\n"));
  int repeatCounter = 0;
  while(!client.available() && repeatCounter < 10) {
    delay(1000);
    Serial.println(".");
    repeatCounter++;
  }
is anything else i should change? thanks a lot for the help.

magnum129, 2019-03-22:
as of 2.10 it's been switched to a new time client, that may work for you. Please give it a try.

Qrome, 2019-03-22:
Thanks to @magnum129 -- the Marquee Scroller v2.10 includes TimeZoneDB service that resolves the issue here.

dagopeter, 2019-06-18:
Here I have my problem copied at serial output - it will connect to weather-server and time-server, but at data process comes always message - wrong api key. But I cannot test it on an other modus. What is wrong?
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

Qrome, 2019-06-18:
Have you confirmed that your API key works?   It looks like a valid response telling you that you have an Invalid API key for the TimeZone service.

dagopeter, 2019-06-18:
Hi Qrome - thanks for reply - no, I have an free api key and did not find out how to change it. It seems, that I would have to pay for a regular service - isn't it ?

dagopeter, 2019-06-18:
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
.. here it is - all looks good but there is no query, so that it seems that non has used it  - me too :-)

dagopeter, 2019-06-18:
.. I will try it tomorrow to get a new one with another email address perhaps :-)

dagopeter, 2019-06-19:
It is a pitty - also my new API key reacts in the same manner.
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
It must have another reason ....  :-(

Qrome, 2019-06-19:
Sure enough -- you have NOT activated your account with TimeZoneDB -- they send you an email with the KEY in the email -- however just above that they give you a link to activate the account.   If you do not do this, it will not work.   This is how they verify that you have a valid email address on the account.

How do I know this?   I just went through and created another key.

Go back to your email and click on the activate account link.

dagopeter, 2019-06-19:
Tataaa ... you are right ---- I cannot believe that I had forgotten it twice , but it has to be real :-) In that moment I tipped on that link and restarted my WEMOS Board the right Date and Time happend lightning fas - thank you so much - now I' m happy with this and - sure - I will look at the whole thing much deeper than before :-)

Qrome, 2019-06-19:
Cool, glad it is working for you.   You may want to delete the photos in your posts as they have your key in them.     Thanks for the update.

dagopeter, 2019-06-19:
Thank you again - I have deleted it - could be better so :-)  Have a nice time!

Closed 2019-06-19.

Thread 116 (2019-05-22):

Weather Data Error Unathorized

acestu, 2019-05-22:
Hi,
After putting my API and city id in settings for openweather.org I get a Weather Data Error saying that it is Unathorized, have they changed API's for Free accounts ?

thanks
Stuart

Qrome, 2019-05-22:
You can test your API key directly with them.   Mine is currently working and I am not aware of any changes.

acestu, 2019-05-27:
Hi Qrome, I have tested my openweathermap API in Postman using the same City ID, it returns the neccesary information and works fine, I created a new API and pasted it into the Marquee sketch togethor with the same city ID however I still get Weather Data Error 401 Unauthorised on the matrix, just to be certain this is the line from the sketch for city id:
int CityIDs[] = { 2643266 }; //Only USE ONE for weather marquee

Thanks
Stuart

Qrome, 2019-05-27:
@acestu -- If you are updating the Settings.h file then reloading it -- this will not update the settings.   It is noted in the Rreadme file.   Have you tried updating the API Key and City ID using the Web Interface?

acestu, 2019-05-27:
Hi Qrome, allthough the matrix gives an ip address, if I try to connect on computer or phone, I see a quick blink on the board led but it will not connect, I did think that the board maybee faulty so I uploaded the MDParola example of esp8266 scrolling message which worked perfectly with the webserver page for setting the message etc. I then reuploaded the Marquee sketch and it is the same
Thanks
Stuart

acestu, 2019-05-27:
Hi Qrome, I have just checked how to return the D1 to factory settings and it is quite long winded so I will order some new boards and try again.

Thanks
Stuart

Qrome, 2019-05-27:
Make sure you have the ESP8266 Core 2.5.0 (not 2.5.1)  -- also make sure you specify 1M SPIFFS -- the application uses SPIFFS.

acestu, 2019-05-27:
Ok Thanks for the info, it's a shame it dosen't work with the D1 mini Pro , I have lots of them lying around

Thanks Again
Stuart

Qrome, 2019-05-27:
It does work with the D1 mini pro -- I use them.  Can you send me a link to the board you are using?

acestu, 2019-05-27:
Hi Qrome, I don't have a link because I have had lots of these boards for years and I can't remember where I got them from, if I use a mini pro what settings should I use ?

Thanks
Stuart

Qrome, 2019-05-27:
Make sure you have the:
- ESP8266 Core 2.5.0 installed
- Select the board "LOLIN(WEMOS) D1 R2 & mini" board
- Select Flash Size "4M (1M SPIFFS)"

If that compiles and loads, then I would suspect it will run.   Try pulling up the web interface.   Again -- important to have the ESP8266 Core at 2.5.0.

acestu, 2019-05-28:
Hi Qrome, I tried flashing a D1 mini pro tonight I left spiffs on 14M spiffs, now the SSID for the device appears about 5 mins later, I set my WIFI in the webpage that comes up, however after that the Matrix scrolls with the IP address but when I try to go to the page on computer laptop or phone it just says waiting for page, I know you said make sure you have core 2.5.0. but how ddo I know or how can I find out what core it has ?

Thanks
Stuart

Qrome, 2019-05-28:
Open Arduino --> Tools --> Boards --> Boards Manager...
Then Filter on ESP8266 -- you should see what you have installed there and set it to 2.5.0.

acestu, 2019-05-28:
Hi Qrome, Sucsess, I thought the core was the board firmware not the software that is used to program them, everything seems to work now apart from the news but that's another story, thanks so much for your help and percivering with me, I will close the thread now

thanks
Stuart

Qrome, 2019-05-29:
Just an update on this, I spent some time with the code to make it compatible with the latest version of ESP8266 Core 2.5.2  -- you can now get the latest Marquee Scroller 2.14

Closed 2019-05-28.

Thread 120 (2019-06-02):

News hit and miss

acestu, 2019-06-02:
Hi Qrome,

When I first got the Marquee working I pasted my news API into the box but the news did not turn up on the Matrix only the source title ie google-news-uk , I noticed on the Marquee web page that it was still asking me to configure News even though my news api was already pased into the box, after unplugging the marquee the next time I plugged it in  the News was working on the marquee and it was no longer asking me to configure it on the web page, however after unplugging and plugging in again the News has gone again and I am being asked to configure it but with my api already in the box if i press save it returns to the homepage and is still asking me to configure news

thanks
Stuart

acestu, 2019-06-02:
Hi Qrome,

I have noticed that if you choose a different source then sometimes it starts working, could news.api be at fault with sperodical uptime ?

thanks
Stuart

Qrome, 2019-06-02:
Not all languages are supported -- due to the characters not supported by the fonts.

Qrome, 2019-06-02:
Make sure you are running the latest code of Marquee Scroller -- you can also view the Serial Monitor in Arduino IDE over your COM port and baud rate of 115200 -- you will be able to see the details of the news api call and stuff like that.

acestu, 2019-06-02:
Hi Qrome,
The sources I choose are English as one minute they are working and the next they are not, could this be a news.api issue ?

thanks
Stuart

Qrome, 2019-06-02:
I have not seen that issue.  If you can view the details using the Arduino Serial monitor -- it would be able to provide you more information.

acestu, 2019-06-02:
Hi Qrome,
I have just updated from 213 to 214  Now the wind speed is reported on marquee as 210  and on the web page it says:   kph WIND

The News does the same thing and in the serial monitor it says:

connection for news data failed: http://newsapi.org/v2/top-headlines?sources=hacker-news&apiKey=a58b7f4618544a7693300f44********

So I don't know if this means anything to you ?

Thanks
Stuart
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

Qrome, 2019-06-02:
The 210 degrees is the direction of the wind followed by the speed.   Wind direction is new.   The error you are seeing is connectivity.   Looks like connectivity issue.

acestu, 2019-06-02:
Hi Qrome,

Yes wind makes sense now you have said direction,  It has just called for news again in monitor window same thing failed allthough I am blatently connected to the internet and watching TVplayer, I am using Nord VPN could this be anything to do with it  or maybe anti virus software, seems funny that it is intermittent.

thanks
Stuart

Qrome, 2019-06-02:
What version of the ESP8266 Core did you compile with?   Make sure you are using 2.5.0 or later -- the binary in the download was compiled with ESP8266 Core 2.5.2 -- see if that helps.

Your internet access is not the question -- it is the device connection stability.  What is the signal strength?   You say it works now and then -- so that is odd.   You are the only one reporting an issue on this.

acestu, 2019-06-02:
H Qrome,
I have just been experimenting with connections and vpn, when connected with vpn my internet icon on the taskbar (win10) has a yellow exclamation mark and says unidentified network No internet access which i think is my vpn connection , browser and other connected items work, however if I dissconnect the vpn the icon now says that i have internet so if I unplug then plug the marquee back in then the news appears, I will try with core 2.5.2 now like you say

Thanks
Stuart

Qrome, 2019-06-02:
The Marquee Scroller should have it's own IP from your router with public internet access through your gateway -- not sure why your Windows 10 VPN would have any affect on the clocks internet access.   I have no idea how you are configuring your network, but I have a feeling it is something on that end.

acestu, 2019-06-03:
Hi Qrome,
Just updated everything, new board and it seems to be behaving itself, great work, thank you
Stuart

Qrome, 2019-06-03:
That is good news.   Thanks for the update.

Closed 2019-06-03.

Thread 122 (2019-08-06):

Drive a LED ON/OFF via WebServer

Neeraj-Ch, 2019-08-06:
Hi Qrome,

In last few days i have tried my best to integrate a small code to drive a PIN of ESP8266 ON/OFF via web server, but didn't suceeded. I Want to drive a relay/AC Load via the web server.
Actually i am not proficient in Coding.

So require some of your time & Skills.
Please if you can integrate a code to Drive a Relay.

Thanks

Neeraj-Ch, 2019-08-13:
Anybody else, if can do help of me. Please

Neeraj-Ch, 2019-08-19:
Anybody there ?

fixyourlan, 2019-08-19:
Search google for help. There are many sites that show how to do this with example code. Search how to program esp8266 to control a relay.  This is not the place to be asking for help for this if it is not related to this project!

Jim Bazar

On Aug 18, 2019, at 9:21 PM, Neeraj-Ch <notifications@github.com> wrote:

Anybody there ?

—
You are receiving this because you are subscribed to this thread.
Reply to this email directly, view it on GitHub, or mute the thread.

Neeraj-Ch, 2019-08-19:
Hi Zim, Actually i have many codes for this. The codes are simple. I had done a lot of googling. But integrating code is a Nightmare for me. That's why my all hope is to you all. I am helpless.
By the way thanks for replying.

Neeraj-Ch, 2019-12-07:
Hi Qrome & everyone here.

I tried everything to Drive an LED via an Option in Web Server/Interface of your Code.

Actually i wanted to integrate an LED in Marquee-Scroller, which can be controlled by Web-Interface of it. But found No success. ☹️

I think an LED Light can be much useful during Night & the way controlling it might be Fun.

Problem for me is Altering the code. I have no problems for Electronics stuff.

It's been a long time trying to do so (~4 Months) You all are my last hope.

Neeraj-Ch, 2019-12-13:
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

Anybody here interested to Help?

Closed 2020-04-13.

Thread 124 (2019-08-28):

Unordered display on the led array

DensRever, 2019-08-28:
I just ordered a led matrix from bangood, but the display is messy.
After search the type of the matrix is   ICSTATION_HW.
Is this matrix compatible with this project?
Thanks for your help.

Qrome, 2019-08-28:
Yes, it should be supported.   Some brands have the LED set in different rotations.   Try changing the ledRotation value in the Settings.h file -- this should correct it for you.

fixyourlan, 2019-08-28:
Attach a picture of what you mean “messy”!

Jim Bazar

On Aug 28, 2019, at 3:09 PM, DensRever <notifications@github.com> wrote:

I just ordered a led matrix from bangood, but the display is messy.
After search the type of the matrix is   ICSTATION_HW.
Is this matrix compatible with this project?
Thanks for your help.

—
You are receiving this because you are subscribed to this thread.
Reply to this email directly, view it on GitHub, or mute the thread.

Qrome, 2019-08-28:
The other thing to check is:

Set 1M SPIFFS -- this project requires SPIFFS for saving and reading configuration settings.

This is part of the readme file -- if you do not set this in the Arduino IDE then when it boots up... the LEDS may look like a mess.

DensRever, 2019-08-29:
Hello and thank's for your help.
BEFORE
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

In the setting.h i make changes like this : The changes are writed bold.

// Display Settings
// CLK -> D5 (SCK)
// CS  -> D6
// DIN -> D7 (MOSI)
const int pinCS = D6; // Attach CS to this pin, DIN to MOSI and CLK to SCK (cf http://arduino.cc/en/Reference/SPI )
int displayIntensity = 1;  //(This can be set from 0 - 15)
### **const int numberOfHorizontalDisplays = 8**; // default 4 for standard 4 x 1 display Max size of 16
const int numberOfVerticalDisplays = 1; // default 1 for a single row height
/* set ledRotation for LED Display panels (3 is default)
0: no rotation
1: 90 degrees clockwise
2: 180 degrees
3: 90 degrees counter clockwise (default)
*/
### **### int ledRotation = 1;**

const int numberOfHorizontalDisplays = 8 - for 2 modules of 4 matrix leds
ledRotation = 1 - for the matrix "led" who comes from Bangood.

Now all works correctly

As Qrome says, you must read the Readme file carefully for the IDE arduino to work properly. Thank you very much to the people who helped.
Cordially.
Denis.

Qrome, 2019-08-29:
Glad you got it working.

DensRever, 2019-08-29:
Where's my comments ?

Closed 2019-08-29.

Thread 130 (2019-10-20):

Settings.h error compiling Delcaration.

kd4pba, 2019-10-20:
Forgive my ignorance but I seem to have issues compiling that trace back to settings.h
In file included from D:\new\marquee-scroller-master\marquee\marquee.ino:28:0:

Settings.h:86:19: error: 'D6' was not declared in this scope

 const int pinCS = D6; // Attach CS to this pin, DIN to MOSI and CLK to SCK (cf http://arduino.cc/en/Reference/SPI )

If this is changed to 6 from D6 it compiles however additional errors related to pin not being declared appear.  Changing that from D2 to 2 allows me to compile however this appears to be non functional as I can not communicate with the 8266.

Thinking I screwed this up I went back to the stock files and pulled them again.  I get the same errors so I am a little confused as to what is wrong.

Qrome, 2019-10-20:
It sounds like you may not have the correct board selected in the Arduino IDE.  Select the one listed in the Readme.md file.

Closed 2019-10-20.

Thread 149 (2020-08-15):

Can't compile

osb99, 2020-08-15:
Hi, I get this error code when compiling, please can someone help?

In file included from /Users/jamesosborne/Library/Arduino15/packages/esp8266/hardware/esp8266/2.7.4/tools/sdk/libc/xtensa-lx106-elf/include/sys/stdio.h:6:0,
                 from /Users/jamesosborne/Library/Arduino15/packages/esp8266/hardware/esp8266/2.7.4/tools/sdk/libc/xtensa-lx106-elf/include/stdio.h:63,
                 from /Users/jamesosborne/Library/Arduino15/packages/esp8266/hardware/esp8266/2.7.4/cores/esp8266/Arduino.h:32,
                 from sketch/marquee.ino.cpp:1:
/Users/jamesosborne/Library/Arduino15/packages/esp8266/hardware/esp8266/2.7.4/tools/sdk/libc/xtensa-lx106-elf/include/sys/pgmspace.h:25:130: error: 'const char HTTP_HEAD []' redeclared as different kind of symbol
   #define PROGMEM __attribute__((section( "\".irom.text." __FILE__ "." __STRINGIZE(__LINE__) "."  __STRINGIZE(__COUNTER__) "\"")))
                                                                                                                                  ^
/Users/jamesosborne/Documents/Arduino/libraries/WiFiManager/WiFiManager.h:25:24: note: in expansion of macro 'PROGMEM'
 const char HTTP_HEAD[] PROGMEM            = "<!DOCTYPE html><html lang=\"en\"><head><meta name=\"viewport\" content=\"width=device-width, initial-scale=1, user-scalable=no\"/><title>{v}</title>";
                        ^
In file included from sketch/Settings.h:39:0,
                 from /Users/jamesosborne/Downloads/marquee-scroller-master/marquee/marquee.ino:28:
/Users/jamesosborne/Library/Arduino15/packages/esp8266/hardware/esp8266/2.7.4/libraries/ESP8266WebServer/src/ESP8266WebServer.h:34:39: error: previous declaration of 'HTTPMethod HTTP_HEAD'
 enum HTTPMethod { HTTP_ANY, HTTP_GET, HTTP_HEAD, HTTP_POST, HTTP_PUT, HTTP_PATCH, HTTP_DELETE, HTTP_OPTIONS };
                                       ^
exit status 1
Error compiling for board LOLIN(WEMOS) D1 R2 & mini.

Qrome, 2020-08-15:
You need to use ESP8266 core 2.5.2.

osb99, 2020-08-15:
> You need to use ESP8266 core 2.5.2.

How do I do that?

osb99, 2020-08-15:
> You need to use ESP8266 core 2.5.2.

Perfect, thank you!

Closed 2020-08-15.

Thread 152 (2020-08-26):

Marquee-Scroller Web page Password User Name recovery

LenK13, 2020-08-26:
To all concerned:
I realize this is not the normal method of making contact with you and the Team.  But I need some serious help. I just finished replicating the You Tube project posted for the Weather Marque Clock News Station ("ESP8266 Wemos Clock News Weather Scrolling Marquee | Arduino").  Reference:  "https://www.youtube.com/watch?v=_jpMv5YaToE".

Outstanding Video.  This is the FIRST Time I have been able to get a ESP Module to work for me.  That and a previous related Video posted, allowed me to get the Max7219 working properly for the first time.  Good Stuff. The information is sound and does work.

Problem I have is after all the work hours of debugging and trying to understand "CODING", making corrections/adjustments, registering the weather sites, news sites and time site to receive API Keys, I am now locked out of the "Weather Marque Web page".  The USER Name and Password will not allow me back into the settings to make adjustments. How is it that I can reset this?  Or can you reset this for me?

I really would appreciate your support in resolving this issue "Recovery - User Name & Password".  Thank you in advance.

Respectfully,

Leonard

Qrome, 2020-08-26:
Leonard,

Have the unit pluged into your comuter, have the Serial Monitor open and using baud 115200.  Press the reset button on the Wemos D1 Mini -- when it boots up, it will display the settings including the user / password.

LenK13, 2020-08-26:
Qrome,

Thank you so much for your quick response.!  I did as you recommended and Wa-La..!  Serial Monitor showed USER Name and Password, just as you stated.

Thank you..  Truly appreciate your support regarding this matter.

Respectfully,

Leonard

LenK13, 2020-08-29:
Thank You for the information/solution.
Explanation was prompt, clear, concise and functional.

Respectfully,
Leonard
    On Wednesday, August 26, 2020, 12:51:01 PM PDT, Qrome <notifications@github.com> wrote:

Leonard,

Have the unit pluged into your comuter, have the Serial Monitor open and using baud 115200. Press the reset button on the Wemos D1 Mini -- when it boots up, it will display the settings including the user / password.

—
You are receiving this because you authored the thread.
Reply to this email directly, view it on GitHub, or unsubscribe.

Closed 2020-08-26.

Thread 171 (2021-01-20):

compiling error

Burhanej, 2021-01-20:
http.begin(apiGetData);
HTTPClient::begin' declared with attribute error: obsolete API, use ::begin(WiFiClient, url)

Qrome, 2021-01-20:
Make sure you are using all the correct versions of the library files mentioned in the readme file.

gavvyt, 2021-07-03:
I also had this issue and found the way around it was to downgrade the board library for the ESP8266 to version 2.5.2
(this was done in the Arduino application on my Mac)

billbee, 2021-12-13:
Serial.println("Getting News Data");
  Serial.println(apiGetData);
  WiFiClient client;
  HTTPClient http;
  http.begin(client, apiGetData);
  int httpCode = http.GET();

this worked on mine.

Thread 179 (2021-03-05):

Two strange boxes.

Talha909, 2021-03-05:
All things are working. But there are two strange boxes. Whats the reason for this.
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
![Uploading IMG_9878.JPG…]()

Qrome, 2021-03-05:
Make sure all the pins for those two panels are seated correctly in the board.

Talha909, 2021-03-05:
wire are in correct order. What are the other possibilities.

Qrome, 2021-03-05:
I am talking about the big squaqre pannels that have a block of LEDs on them.  They pop into the board.  I have seen some that are not seated into the main LED board and cause this.  I am not talking about the 5 wires that come off the side of the board.

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

There are 4 panels of LEDs... Check that all the pins on them are inserted correctly and that none of them are bent.

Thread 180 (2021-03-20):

Degree Sign missing

njordan77, 2021-03-20:
I guess its no real issue but i was asking myself why there is no °Sign @temperatures. Is it a matter of place on the display?
The reason is that people first looking at this great implementation are little confused about the temperature displayed.

Is there a plan or a reason for not using the ° sign?
Thanks a lot
Norbert
btw, very nice project, really love your implementation....

Qrome, 2021-03-20:
The fonts that are used do not have that symbol. Or it would have been used. Sorry if it confuses people. But that is how it is right now.

brianmiller1956, 2021-03-20:
Hi, Sorry to butt in, I added the degree symbol to both the present temperature and the hi/lo temp, the lines just need +char(247) adding thus, it is included in the glcdfont file.
Brian.

if (SHOW_CITY) {
        msg += weatherClient.getCity(0) + ".  ";//added full stop to place name
      }
      msg += temperature + char(247) + getTempSymbol() + "  "; //added char(247) degree symbol

      //show high/low temperature, added space to Hi/Lo, Humidity, Barometer
      if (SHOW_HIGHLOW) {
        msg += "High/Low: " + weatherClient.getHigh(0) + "/" + weatherClient.getLow(0) + char(247) + getTempSymbol() + "  ";//added char(247) degree symbol
      }

Sent from Mail for Windows 10

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

njordan77, 2021-03-20:
wow, thanks a lot for the feedback. i did not want to put a request on the table, but more understand if it was a matter of discussion or why its not implemented.

@Qrome would it be possible to add the code from @brianmiller1956 and provide a new BIN version. That would help me to not get stuck with libraries,.....

Many Thanks
Norbert

brianmiller1956, 2021-03-20:
Hi Norbert,
Sorry to butt in, I added the degree symbol a while ago from another fork, it is just a case of adding +char(247) in two places the first puts it in the present temp the second the hi/lo temp. The font file does have this defined. I cant give you the line numbers but it is easy to find in the main loop.

msg += temperature + char(247) + getTempSymbol() + "  "; //added char(247) degree symbol

      //show high/low temperature, added space to Hi/Lo, Humidity, Barometer
      if (SHOW_HIGHLOW) {
        msg += "High/Low: " + weatherClient.getHigh(0) + "/" + weatherClient.getLow(0) + char(247) + getTempSymbol() + "  ";//added char(247) degree symbol
      }

Brian

Sent from Mail for Windows 10

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

Qrome, 2021-03-20:
I will take a look at it but I will probably be adding it to the function get temperature symbol so it doesn't have to be injected everywhere.

Qrome, 2021-03-20:
Thanks by the way.   I am testing it by just adding it to the following function:

`String getTempSymbol() {
  String rtnValue = "F";
  if (IS_METRIC) {
    rtnValue = "C";
  }
  return char(247) + rtnValue;
}`

brianmiller1956, 2021-03-20:
Many thanks, this is a really great project, I am a newcomer to the arduino ide but have learnt a lot from this project, it really is easy to add cosmetic changes.
P.s. any chance of adding sunrise/sunset times to the weather?

Sent from my iPad Pro

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

Qrome, 2021-03-20:
@njordan77 -- thanks for the info.

I have created a 3.17 branch with binaries that have the updated degree symbol.  I have tested it in both the web interface and in the clock.  I have also updated it for the wide clock version and tested there.   This has not yet been merged to master, but you can get the binary and see the changes here:

https://github.com/Qrome/marquee-scroller/tree/release/3.17

As for adding lots of display options -- I kind of went down that route in the beginning, but have been trying to simplify a bit.   I will consider it.  Thanks again.

brianmiller1956, 2021-03-21:
Hi, just to update you, I added your modification for the degree symbol and removed mine, it works in the scroller fine but the web interface doesn’t like it, I am using an Apple iPad and have tried both safari and google chrome with the same results. I have attached screen shot.

Sent from my iPad Pro

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

Qrome, 2021-03-21:
@brianmiller1956 -- yeah, sorry about that.  The code snip I shared above was not what ended up in the 3.17 branch.  This is what I ended up doing after testing the web interface.

String getTempSymbol() {
  return getTempSymbol(false);
}

String getTempSymbol(bool forWeb) {
  String rtnValue = "F";
  if (IS_METRIC) {
    rtnValue = "C";
  }
  if (forWeb) {
    rtnValue = "°" + rtnValue;
  } else {
    rtnValue = char(247) + rtnValue;
  }
  return rtnValue;
}

Then in the two lines where it calls to get the temp symbol for the web interface I updated it to:

    html += temperature + " " + getTempSymbol(true) + "<br>";
    html += weatherClient.getHigh(0) + "/" + weatherClient.getLow(0) + " " + getTempSymbol(true) + "<br>";

I hope that helps.   Thanks again for sharing.

brianmiller1956, 2021-03-21:
Just to confirm, I have added these changes and they work well, many thanks.

Sent from my iPad Pro

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

Qrome, 2021-03-21:
@brianmiller1956 thanks again.

njordan77, 2021-03-21:
Thanks to both of you to make this happen so quick!!!!!!
I'm curious to see how the alignment works when there is a two digits temp to be presented. Right now its +2°C...so plenty of space on the wide display. guess will be crowded when it reaches a second digit.

Qrome, 2021-03-21:
@njordan77 -- in the 3.17 branch I removed one of the spaces between the time and the temp -- so it should be just fine.  I live a place that we see things like 114°F -- so that now adds another character in there.  It should be fine though.

Closed 2021-03-21.

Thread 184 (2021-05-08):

number of modules

MichaelMichaelMichaelMichaelMichael, 2021-05-08:
Hi, I'd like to use 40 modules in a row (see photos attached) and I've set numberOfHorizontalDisplays = 40, but I cannot achieve one large coherent line.

I've seen the comment in Settings.h: "display Max size of 16", yes, but the underlying Max72xxPanel is reported not to have that limit (anymore), so I believe I should be able to actually use it, or what is actually the limiting factor?

I have inserted a capacitor between VIN and GND at the very beginning of the chain in order to avoid any strange effects.
What's working somehow, but not "fine" is setting numberOfHorizontalDisplays = 20, which e.g. shows the output in the photo down below, i.e. a split output. Any number of <20 also works and brings out more splitted sections with the same content each. Any number >20 brings garbled output.

I'm using a dedicated 5V AC adapter with 3.0 Amps Current (15 W) and I'm decoupled from the PC with Arduino on.

Any idea what could help me solve the problem? Thanks in advance!

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

MichaelMichaelMichaelMichaelMichael, 2021-05-08:
I forgot to mention that in [MD_MAX72XX](https://github.com/MajicDesigns/MD_MAX72XX/) terms, the modules are [FC-16 modules](https://majicdesigns.github.io/MD_MAX72XX/page_f_c16.html), with that library, the animations are running flawlessly over all 40 modules ... what would be the equivalent in [arduino-Max72xxPanel](https://github.com/markruys/arduino-Max72xxPanel) terms?

Labeey, 2022-04-04:
Maybe the issue is with the clock pin. Im just guessing here.  Since the data and clock pins are in series there might be capacitance or resistance that is interfering with the data.

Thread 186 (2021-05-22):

Doesnt compile now :(

laneyweb, 2021-05-22:
I had this working a few weeks ago. I tried to recompile today and get this:
anyone offer any help please?

```
C:\Stuff\Electronics\marquee-scroller-master\marquee\NewsApiClient.cpp: In member function 'void NewsApiClient::updateNews()':
NewsApiClient.cpp:49:13: error: call to 'HTTPClient::begin' declared with attribute error: obsolete API, use ::begin(WiFiClient, url)
   49 |   http.begin(apiGetData);
      |   ~~~~~~~~~~^~~~~~~~~~~~
C:\Stuff\Electronics\marquee-scroller-master\marquee\PiHoleClient.cpp: In member function 'void PiHoleClient::getGraphData(String, int)':
PiHoleClient.cpp:155:13: error: call to 'HTTPClient::begin' declared with attribute error: obsolete API, use ::begin(WiFiClient, url)
  155 |   http.begin(apiGetData);
      |   ~~~~~~~~~~^~~~~~~~~~~~
C:\Stuff\Electronics\marquee-scroller-master\marquee\BitcoinApiClient.cpp: In member function 'void BitcoinApiClient::updateBitcoinData(String)':
BitcoinApiClient.cpp:44:13: error: call to 'HTTPClient::begin' declared with attribute error: obsolete API, use ::begin(WiFiClient, url)
   44 |   http.begin(apiGetData);
      |   ~~~~~~~~~~^~~~~~~~~~~~
C:\Stuff\Electronics\marquee-scroller-master\marquee\PiHoleClient.cpp: In member function 'void PiHoleClient::getTopClientsBlocked(String, int, String)':
PiHoleClient.cpp:105:13: error: call to 'HTTPClient::begin' declared with attribute error: obsolete API, use ::begin(WiFiClient, url)
  105 |   http.begin(apiGetData);// get the result
      |   ~~~~~~~~~~^~~~~~~~~~~~
C:\Stuff\Electronics\marquee-scroller-master\marquee\PiHoleClient.cpp: In member function 'void PiHoleClient::getPiHoleData(String, int)':
PiHoleClient.cpp:38:13: error: call to 'HTTPClient::begin' declared with attribute error: obsolete API, use ::begin(WiFiClient, url)
   38 |   http.begin(apiGetData);// get the result
      |   ~~~~~~~~~~^~~~~~~~~~~~
exit status 1
call to 'HTTPClient::begin' declared with attribute error: obsolete API, use ::begin(WiFiClient, url)

```

Qrome, 2021-05-22:
What board do you have selected and what version of ESP8266 core platform do you have installed?

laneyweb, 2021-05-22:
Hi there, thank you for your reply!
I have a Wemos D1 Mini and have the board: LOLIN Wemos D1 R1
I am not sure how to check the ESP8266 platform, sorry, are you able to point me to where I should look in the Arduino App?

Qrome, 2021-05-22:
Under the Board Manager -- filter it on esp8266 -- this should show you what ESP8266 core version you have installed.  My guess is you have upgraded.  This project was written for version 2.5.2.

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

brianmiller1956, 2021-05-22:
Hi, I saw this post and have checked this, I updated the esp8266 core to v3.0.0 earlier this week and also found that marquee scroller doesn’t compile and gives the identical errors, I have reinstalled v2.7.4 and it compiled first time. Hope this helps.

Sent from my iPad Pro

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

laneyweb, 2021-05-22:
Thank you very much both of you. I had indeed upgraded to 3... - installed 2.5.2 again and all is well :)

Thanks again for both of your prompt replies.

brianmiller1956, 2021-05-22:
Hi, I went back to 2.7.4 the previous version, might be better than 2.5.2, it does compile ok.

Sent from my iPad Pro

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

Closed 2021-05-22.

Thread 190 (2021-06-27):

Add Spotify now playing

finnie2006, 2021-06-27:
Add a feature to show the now playing song on spotify

victor7376, 2021-06-28:
Spotify requires an https connection and some other features to be added for it to work.  As the default marquee doesn't have the https feature, it would need to be programmed into it.

I did take a quick look at that.

finnie2006, 2021-06-29:
oh, also i think a https webserver is to intensive for a wemos (esp8266) maybe with a esp32 u can use https

finnie2006, 2021-06-29:
Maybe using this
https://github.com/witnessmenow/spotify-api-arduino/blob/master/examples/esp8266/getCurrentlyPlaying/getCurrentlyPlaying.ino

victor7376, 2021-06-29:
Yes I know about that, it can use both ESP32 & 8266.  Making the marquee with the basic programming can handle the https requests.

finnie2006, 2021-06-29:
Can u help me add it

victor7376, 2021-06-29:
To get an https connection working perfectly, you just need to go through the marquee.ino file and remove all the parts you wont be used but mostly the wifimanager.  I have tried to get an https connection to work with the wifimanager with weather and time but the connections fail.

I'll take a look hopefully today to see if I can add the playing now feature of spotify to work with the basic marquee.

My basic marquee doesnt have the wifimanager, but does allow updates via wifi (OTA).

finnie2006, 2021-06-29:
Oki, will u add it here? https://github.com/victor7376/marquee-scroller

victor7376, 2021-06-29:
the clock is still there, I just dont use the weather, news, ocotoprint, bitcoin etc.

finnie2006, 2021-06-29:
So when u add the spotify now playing function clock/ time will still work?

victor7376, 2021-06-29:
Yes hopefully, all you're doing is bragging certain parts within the spotify cpp to retrieve the 'now playing' and putting it into the scrolling clock / data message.

victor7376, 2021-06-29:
This is my basic marquee.

`//==========================================
//  Difference between ESP32 and ESP8266
//  ESP32 is more powerful with faster WiFi
//==========================================
//default libraries
#include <SPI.h>
#include <Adafruit_GFX.h> // --> https://github.com/adafruit/Adafruit-GFX-Library
#include "Max72xxPanel.h" // --> https://github.com/markruys/arduino-Max72xxPanel
#include "TimeDB.h"
#include <WiFiClientSecure.h>
#include <ArduinoOTA.h>
#include <WiFiUdp.h>

//#define ESP32           // Unncomment if using ESP32 or Comment out if using ESP8266
#ifdef ESP32
  #include <WiFi.h>
  #include <ESPmDNS.h>
#else
  #include <ESP8266WiFi.h>
  #include <ESP8266mDNS.h>
#endif

//============================ Your WIFI Network Details ==============================
const char* ssid     = "";          // Your SSID / WiFi Network
const char* password = "";  // Your SSID / WiFi Password
//=====================================================================================

//================================ TimezoneDB Settings ================================
String TIMEDBKEY = ""; // Your API Key from https://timezonedb.com/register

// Location taaken from TimezoneDB - can be taken from the homepage
String LAT = "";          // Latitude
String LON = "";          // Longitude
//=====================================================================================

/* Useful Constants */
#define SECS_PER_MIN  (60UL)
#define SECS_PER_HOUR (3600UL)
#define SECS_PER_DAY  (SECS_PER_HOUR * 24L)

// Display Settings
// CLK -> D5 (SCK)
// CS  -> D6
// DIN -> D7 (MOSI)

const int pinCS = D6; // Attach CS to this pin, DIN to MOSI and CLK to SCK (cf http://arduino.cc/en/Reference/SPI )

// Here you can choose how many displays you have - Displays come in a set of 4, so double would be 8 etc
const int numberOfHorizontalDisplays = 16; // default 4 for standard 4 x 1 display Max size of 24 works
const int numberOfVerticalDisplays = 1; // default 1 for a single row height

int displayIntensity = 1;  //(This can be set from 0 - 15) - how bright you want the display
int minutesBetweenDataRefresh = 15;  // Time in minutes between data refresh (default 15 minutes)
int minutesBetweenScrolling = 3; // Time in minutes between scrolling data (default 1 minutes and max is 10)
int displayScrollSpeed = 25; // In milliseconds -- Configurable by the web UI (slow = 35, normal = 25, fast = 15, very fast = 5)
boolean flashOnSeconds = true; // when true the : character in the time will flash on and off as a seconds indicator
boolean IS_24HOUR = true; // 23:00 millitary 24 hour clock
boolean IS_PM = true; // Show PM indicator on Clock when in AM/PM mode
int ledRotation = 3;
String timeDisplayTurnsOn = "08:30";  // 24 Hour Format HH:MM -- Leave blank for always on. (ie 05:30)
String timeDisplayTurnsOff = "22:30"; // 24 Hour Format HH:MM -- Leave blank for always on. Both must be set to work.
String marqueeMessage = "";           // Custom Message if wanted

// LED Settings
const int offset = 1;
int refresh = 0;
String message = "hi";
int spacer = 1;  // dots between letters
int width = 5 + spacer; // The font width is 5 pixels + spacer
String Wide_Clock_Style = "3";
Max72xxPanel matrix = Max72xxPanel(pinCS, numberOfHorizontalDisplays, numberOfVerticalDisplays);

// TimeDB - do NOT alter
TimeDB TimeDB("");
String lastMinute = "xx";
int displayRefreshCount = 1;
long lastEpoch = 0;
long firstEpoch = 0;
long displayOffEpoch = 0;
boolean displayOn = true;
// OTA
boolean ENABLE_OTA = true;    // this will allow you to load firmware to the device over WiFi (see OTA for ESP8266)
String OTA_Password = "";     // Set an OTA password here -- leave blank if you don't want to be prompted for password
#define HOSTNAME "Clock-"

// Main program
void setup() {
  // put your setup code here, to run once:
  Serial.begin(115200);
  delay(10);
 //New Line to clear from start garbage
  Serial.println();

  Serial.println();
  Serial.println();
  Serial.println("Booting");
  WiFi.mode(WIFI_STA);
  WiFi.begin(ssid, password);
  while (WiFi.waitForConnectResult() != WL_CONNECTED) {
    Serial.println("Connection Failed! Rebooting...");
    delay(5000);
    ESP.restart();
  }

  Serial.println();

  ArduinoOTA.setHostname(HOSTNAME);

  ArduinoOTA.onStart([]() {
    String type;
    if (ArduinoOTA.getCommand() == U_FLASH) {
      type = "sketch";
    } else { // U_FS
      type = "filesystem";
    }

    // NOTE: if updating FS this would be the place to unmount FS using FS.end()
    Serial.println("Start updating " + type);
  });
  ArduinoOTA.onEnd([]() {
    Serial.println("\nEnd");
  });
  ArduinoOTA.onProgress([](unsigned int progress, unsigned int total) {
    Serial.printf("Progress: %u%%\r", (progress / (total / 100)));
  });
  ArduinoOTA.onError([](ota_error_t error) {
    Serial.printf("Error[%u]: ", error);
    if (error == OTA_AUTH_ERROR) {
      Serial.println("Auth Failed");
    } else if (error == OTA_BEGIN_ERROR) {
      Serial.println("Begin Failed");
    } else if (error == OTA_CONNECT_ERROR) {
      Serial.println("Connect Failed");
    } else if (error == OTA_RECEIVE_ERROR) {
      Serial.println("Receive Failed");
    } else if (error == OTA_END_ERROR) {
      Serial.println("End Failed");
    }
  });
  ArduinoOTA.begin();
  Serial.println("Ready");
  Serial.print("IP address: ");
  Serial.println(WiFi.localIP());

  Serial.println();
  Serial.println("Number of LED Displays: " + String(numberOfHorizontalDisplays));
  // initialize dispaly
  matrix.setIntensity(0); // Use a value between 0 and 15 for brightness

  int maxPos = numberOfHorizontalDisplays * numberOfVerticalDisplays;
  for (int i = 0; i < maxPos; i++) {
    matrix.setRotation(i, ledRotation);
    matrix.setPosition(i, maxPos - i - 1, 0);
  }

  Serial.println("matrix created");
  matrix.fillScreen(LOW); // show black
  centerPrint("- CBate -");
  for (int inx = 0; inx <= 8; inx++) {
    matrix.setIntensity(inx);
    delay(100);
  }
  for (int inx = 15; inx >= 0; inx--) {
    matrix.setIntensity(inx);
    delay(60);
  }
  delay(1000);
  matrix.setIntensity(displayIntensity);
}

// Now for the loop which will run and run....
void loop() {
  // put your main code here, to run repeatedly:
  ArduinoOTA.handle();
  // Get some Time Data to serve
  if ((getMinutesFromLastRefresh() >= minutesBetweenDataRefresh) || lastEpoch == 0) {
    getTimeData();
  }
  checkDisplay(); // this will see if we need to turn it on or off for night mode.

  if (lastMinute != TimeDB.zeroPad(minute())) {
    lastMinute = TimeDB.zeroPad(minute());

    matrix.fillScreen(LOW); // show black

    displayRefreshCount --;
    // Check to see if we need to Scroll some Data
    if (displayRefreshCount <= 0) {
      displayRefreshCount = minutesBetweenScrolling;
      String msg;
      msg += " ";

      msg += TimeDB.getDayName() + ", " + day();
      // Sort out the dates if you can.
      if (day() == 1 || day() == 21 || day() == 31) {
      msg += "st, ";
      } else if (day() == 2 || day() == 22) {
      msg += "nd, ";
      } else if (day() == 3 || day() == 23) {
      msg += "rd, ";
      } else {
      msg += "th, ";
      }

      msg += TimeDB.getMonthName() + ", " + year() +" :";  //  moved day to previous line, added comma after month name, added year display and colon

      msg += marqueeMessage + " "; // custom message

    msg += marqueeMessage + " ";

    msg += ": Next Update: " + getTimeTillUpdate() + " ";

    scrollMessage(msg);
    }
  }

  String currentTime = hourMinutes(false);

// ================================================
// Clock Styles are in this section
// ================================================
    if (numberOfHorizontalDisplays >= 8) {

    // Time plus seconds no flashing colon
    if (Wide_Clock_Style == "1") {
      currentTime += secondsIndicator(false) + TimeDB.zeroPad(second());
      matrix.fillScreen(LOW); // show black
    }
    // Normal clock
    if (Wide_Clock_Style == "2") {
      // No change this is normal clock display
    }

    if (Wide_Clock_Style == "3") {
      String timeSpacer = " ";
      currentTime += secondsIndicator(true) + TimeDB.zeroPad(second()) + timeSpacer + day() + "/" + month() + "/" +year();

      matrix.fillScreen(LOW); // show black
    }
  }
// ================================================
// End of Clock Styles section
// ================================================

  matrix.fillScreen(LOW);
  centerPrint(currentTime, true);
}

void scrollMessage(String msg) {
  msg += " "; // add a space at the end
  for ( int i = 0 ; i < width * msg.length() + matrix.width() - 1 - spacer; i++ ) {

    if (refresh == 1) i = 0;
    refresh = 0;
    matrix.fillScreen(LOW);

    int letter = i / width;
    int x = (matrix.width() - 1) - i % width;
    int y = (matrix.height() - 8) / 2; // center the text vertically
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
finnie2006, 2021-06-29:
and spotify?

victor7376, 2021-06-29:
you would need to make a spotify cpp & h files then add the commands within the basic ino file.  Just make sure to add spotify's fingerprint (8266) or cert (esp32) within the cpp for it to make a connection via https.

victor7376, 2021-06-29:
ok, been doing some testing just to get the current playing track and with postman website I've been able to get the json details of a track I've been playing.  You will need the following to get it to work:

Sign up with spotify developer to get access to their api so you can retrieve the details below:
client ID, client secret, bearer token (for authorisation) and your esp clock set up as a call back url.

At the moment I programmed the d1 mini just to the basic to get the bearer token, once I got that I was able to test on the postman site.

victor7376, 2021-06-29:
Issue with Spotify API is that they refresh the access token so I kept on loosing connection while testing the coding.

I do however know there's another Arduino marquee that does support Spotify, but you will need to get yourself an ESP32.

https://github.com/ElToberino/Tobers_Multidisplay

finnie2006, 2021-06-30:
I readed the readme its also for esp8266

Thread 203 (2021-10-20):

Adding a capacitor to the LED matrix increases the system reliability

leliep, 2021-10-20:
After having a lot of hassle with distorted LEDs in the matrix and unreliable startup behavior after power-on I added a 10uF capacitor to the power pins of the first LED matrix element, see attached picture. This was a great improvement, startup always perfect and not a single scrambled display.

(and, btw, thanks for this nice project!)

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

dexter2111, 2021-11-25:
I had the same issue.
Now is working well.
Thank you.

finnie2006, 2022-02-10:
Will a 1K ressistor or 10k or 220K work?

leliep, 2022-02-10:
> Will a 1K ressistor or 10k or 220K work?

Well, a resistor is not a capacitor. So I don’t think it should work as intended…

finnie2006, 2022-02-10:
oh yea, lol close instantly

finnie2006, 2022-02-20:
What do you mean with constructive input?
(I am dutch)

leliep, 2022-02-20:
Constructive like helpful like constructief

What I mean is that I don’t have any idea what a resistor instead of a capacitor would do. Maybe you can help me to understand…

Groetjes vanuit Duitsland :-)

finnie2006, 2022-02-20:
I just ordered capacitors 😃

mrouillard, 2022-03-07:
> What I mean is that I don’t have any idea what a resistor instead of a capacitor would do. Maybe you can help me to understand…

Have a look here for a *very* simplified introduction:
https://science4fun.info/resistors-capacitors-and-inductors/

davsav, 2022-03-08:
> > What I mean is that I don’t have any idea what a resistor instead of a capacitor would do. Maybe you can help me to understand…
>
> Have a look here for a _very_ simplified introduction: https://science4fun.info/resistors-capacitors-and-inductors/

A capacitor stores a charge, like a small battery except it can charge and discharge much faster than the battery.

One use for a capacitor is to smooth out a power supply.

The purpose of adding a capacitor to the LED matrix between the power and ground pins is so that the capacitor can help power the display as suddenly turning on a lot of the leds at once draws a lot of power and the voltage regulator on the D1 Mini may not be able to provide that much power that fast, which causes it to crash as it gets starved of power.

Using a resistor would likely make things worse as a resistor uses power.

neotherack, 2024-12-27:
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

Hello,

I know this is an old record, but I just wanna learn something about it and also check about my home stock :)

My question is
how did you determine 10uF?
Of course I understand the more "capacity" the better it will behave in terms of current stability, but why 10 uF? :)

In the other side, I got at home a waaaaay smaller capacitor, which is 10 pF
Could this capacitor help? I'm wondering if such difference between 10uF and 10pF, my capacitor may just be provide any noticeable help to the whole circuit.

Regards!

leliep, 2024-12-27:
Dimensioning this capacitor to stabilize the voltage for the circuit is mostly based on experience.

Of course you can dig deeper and try to find the perfect value, but here for me 10uF works pretty well and it can be found on a lot of electronics circuits. (The LED matrices used can use a lot of power, depending on how much of the matrix points are lit, that‘s the main cause for needing some buffering.)

If on the contrary you look at your 10pF capacitor, it is 1/1.000.000 of 10uF and you should be able to imagine for yourself that it in no way can help to buffer power surges like the larger ones do. It‘s like going the first meter of a 1000km walk.

Best regards, -pl

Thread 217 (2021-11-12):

Hi/Lo Temp decimals

ik0adr, 2021-11-12:
Hi and thanks for the nice work.
Would it be possible to have Hi/Lo Temps shown as integers, without decimals?
I see this cyted in some pull request, but in current 2.18 they are shown as XX.XX...
Many thanks again,

Federico from Rome, Italy

Qrome, 2021-11-12:
There have been no pull request on the official code line for this.   Though this is a very simple change.

Edit the OpenWeatherMapClient.cpp file and on line 259 and on 264 rap the returned value with rouncValue().

Example, change the following line 259:

return weathers[index].high;

to

return roundValue(weathers[index].high);

Do the same thing for line 264.

I will include this on the 2.19 -- just so people understand, the high/low, it is the current high and low values of the current weather from several stations in the region.

ik0adr, 2021-11-12:
Ok, thanks for the quick reply and info.
I will wait for 2.19, I uploaded the bin file, much easier 😜

Inviato da iPhone

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

davsav, 2021-11-12:
@ik0adr I too was bothered by the two decimal place temperature conversion and had previously edited and recompiled the code to fix that.

Since the code had to be updated to fix the time issue and I had to do the fix again, I did a fork and my compiled binary is available at

[https://github.com/davsav/marquee-scroller/blob/davsav-patch-round-temp/marquee.ino.d1_mini_2.18a.bin](url)

You can do an over the air update to what I called 2.18a.  Note: I did not compile a wide version, just the narrow since that is what I'm using.

I did a pull request, my first, so forgive me if I screwed it up, which it appears I did as the edited CPP files are not in the files directory.

ik0adr, 2021-11-12:
Sorry, link doesn't work..

Il giorno ven 12 nov 2021 alle ore 18:28 davsav ***@***.***>
ha scritto:

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

ik0adr, 2021-11-12:
Don't mind, it worked like a charm, thanks a lot

davsav, 2021-11-12:
Sorry, my bad.  I fixed it in my post above but here it is again:

[https://github.com/davsav/marquee-scroller/blob/davsav-patch-round-temp/marquee.ino.d1_mini_2.18a.bin](https://github.com/davsav/marquee-scroller/blob/davsav-patch-round-temp/marquee.ino.d1_mini_2.18a.bin)

At that page, click the download button on the right side about half way down.

ik0adr, 2021-11-12:
Thanks!!!

Closed 2021-11-12.

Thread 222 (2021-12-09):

Strange behaviour 2.18wide - Clock stuck/no more movement.

njordan77, 2021-12-09:
I have a very strange annoying issue with v2.18 on several installations in different location (internet different). The clock is stuck on a wrong time....so its frozen.....

Wemos / NodeMCUs in use.

Does anybody else face this issue? Do not remember that this ever happened before on my installations that worked for 1+year.
Thanks,
Norbert

tadder, 2021-12-10:
I have a similar problem. Date is stuck at “Thursday 1st January”. Previously working fine.

njordan77, 2021-12-10:
Maybe it is worth mentioning that it works fine for a few hours or even a day. but when it freezes, there is no return to normal function. Reboot and it works again.

Qrome, 2021-12-10:
@tadder  -- make sure you use 2.18
@njordan77 -- your the first to have this issue.  Make sure you have not maxed out your api connection limits

njordan77, 2021-12-10:
@Qrome thanks for the feedback. the strange thing is that it happens on two installations (not immediately, but within one day and from then onwards its frozen). 'm only using weather API, nothing else. no bicoin, no stocks, no news.....if this is ment by max'ing API limits.

tadder, 2021-12-10:
Thank for your reply, you are right I was on an earlier version. Previously I had the display turned through 180deg and the length for 8 modules. I can see that direct editing of the ‘settings.h’ file is no longer necessary and indeed not possible. However, there does not appear to be a way to change  these two parameters using the Web interface. I did try loading ‘marquee.ino.d1_mini_wide_2.18.bin’ (after re-flashing) but still no luck.
I suspect I am missing something simple, but if you could point me in the right direction I would be grateful.

Qrome, 2021-12-10:
The fields that you can't edit in the web interface still take in the values from the settings.h -- edit that for the number of LEDS and orientation.

njordan77, 2021-12-10:
@Qrome. Sure, forgot to mention TimeZoneAPI, but thats is in addition to WeatherAPI. I did see that nobody else did mention this before. Right now its hard to do a serialmon trace as the clock is on the roof of my carport. will soon (when snow in the roor allows) dismount it and do the monitoring to get more specific information.

matthias1403, 2021-12-17:
Hi,
I had the same experience after several hours or a day (Wemos D1 Mini) that the clock stucks. Looking at the serial output it has shown that the program is trapped in the while loop (TimeDB.cpp:63). I see sometimes a lot of data trash received from the server, which is not plausible. I added locally an exit if this is not ending.....which improves, but this is still not clean.
Overall it looks to me like a memory leak (Speicherschmierer) as I have also seen a serial print fragments where it should not be.

Currently my device is also not at the serial port connected, but I could do it, if it would help.

njordan77, 2021-12-17:
as nobody has this issue (except both of us) my speculation is that the OTA update from 2.17 to 2.18 did kill something/bring flash into this dilemma. Will completely flash with BLANK file and reflash 2.18. Hope that this will resolve the issues i'm having.

tadder, 2021-12-18:
It looks like you are right. I have re-flashed on a blank file system and all looks good.

matthias1403, 2021-12-21:
I have also clean the flash through Arduino IDE (Erase flash --> all flash contents) and burned the 2.18 (unchanged), than I have to reconfigure everything. But after a day the clock is stuck again, showing also 6 active pixels at the first column, which indicates that is trapped in the loop where it waits on data. I have seen 2 occurrences up to now.
Any suggestions to clean the flash in another way to be 100% sure that there is nothing wrong?
And nobody else sees this issue?

Qrome, 2021-12-21:
What is the version of the ESP8266 Core you are using to compile it with?

matthias1403, 2021-12-21:
Currently I took the bin from github, but I tested also with  Core 2.7.4, as the 3.x was not compile clean (something obsolete in httpclient call).

Qrome, 2021-12-21:
Try using the version listed in the Readme.md file.

> esp8266 Core platform version 2.5.2

I know this one works correctly.

matthias1403, 2021-12-24:
Used a compiled build with 2.5.2 now. Stuck after a day. Attached the serial log.
If nobody has this issue this is maybe a HW problem of my sample.....
See attachment:
[serial.log](https://github.com/Qrome/marquee-scroller/files/7773731/serial.log)
There is often crap in the http responses, and also the phrase "essful!" should not be there.

njordan77, 2021-12-24:
I blanked my ESP and did a BIN upload - but again only clock is shown (frozen)......normally it shows temp + clock....even after a day no update nothing. The strange thing is that with the same hardware it worked great on 2.17 (for more than a year without any crash). After the general issue and solved via  2.18 it now has this behavior on 2 individual installations...i'm out of ideas what could be specific to my hardware/setup.

matthias1403, 2021-12-27:
I soldered a new Wemos mini at the display and burned a 2.18 on this untouched device. The behavior is the same again, as it stops running after ~1d.
It is definetivly caused by the wrong data in the http responses, which leads sometimes to an infinitive loop. But what could create this data trash?

nored, 2022-01-02:
I have the same issue... however changing TimeDB.cpp in the following way helped:

  boolean record = false;
  unsigned long MAXTIME = 10000; // timeout (milliseconds) for RUNNING state
  unsigned long startTime = millis();

  while (client.connected() || client.available()) { //connected or data available
    char c = client.read(); //gets byte from ethernet buffer
    if (String(c) == "{") {
      record = true;
    }
    if (record) {
      if (String(c) != "⸮") {
        result = result + c;
      }
    }
    if (String(c) == "}") {
      record = false;
    }
    if ((millis()-startTime) >= MAXTIME) {
      client.stop(); //stop client
      Serial.println("Fetching time data took too long..."); //error message if no client connect
      Serial.println();
      return 20;
    }
  }

There is two possibilities I am addressing here either you get some "⸮" that render the time result unusable or you get an infinite amount of "⸮" and the loop never stops reading so that the clock freezes.

I have not tried this solution for long now but at the moment it seems to help.

BeNeDeLuX, 2022-01-04:
I have also the same problems with my two displays here since 2.18.
So you are not alone. Same behavior -> during Update the clock freezes. Happens around once a week.

brainrecall, 2022-01-09:
I've been having the same issue with a standard width clock for at least a month now. I came to same conclusion that @nored found. I solved it in a different manner, and found three other places where there are possibilities of never-exiting while loops. I made those changes and some other things like platform IO support, on my branch for now (I did not build the bins yet): https://github.com/brainrecall/marquee-scroller

njordan77, 2022-01-09:
wow, thanks - more than happy that others having the same issues.

@Qrome is there a chance to get this into the official code and provide binaries. I'm sorry to not be too much of a coding genius. Thanks Norbert

liuxianhao666, 2022-01-10:
I have always had the same problem. I have had this problem since version 2.15. Now I buy the hardware again and brush 2.18. This problem still exists.

nored, 2022-01-10:
My solution stopped working yesterday... so I swiched to ntpclient. I will test and let you know if it works any better and also deliver a patch if it does.

phenomeus, 2022-01-23:
It’s happening for me too. Time is visible and the left first column is stuck three third.

Running weather, time, Bitcoin, octopi and pihole. Because my clock is on battery I took it nearer to an acces point and let it there.  Suddenly it revived itself and continued working.

brainrecall, 2022-02-28:
@nored I think the time source is only half the problem, the weather code also has a while loop that could never exit and I have seen it die there as well. Take a look at my branch, it should cleanup both those cases.

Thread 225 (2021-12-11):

error compiling

degerang, 2021-12-11:
hello
can i remove bitcoin , newsapi, octoprint, pihole ?
i dont need them and they give compile error

Lasse

Qrome, 2021-12-11:
If you are getting compile errors then you are using the wrong version of ESP8266 core -- please read the readme.md for the versions of libraries.

Qrome, 2021-12-11:
From the Readme file:

Compiling and Loading to Wemos D1
It is recommended to use Arduino IDE. You will need to configure Arduino IDE to work with the Wemos board and USB port and installed the required USB drivers etc.

USB CH340G drivers: https://sparks.gogo.co.nz/ch340.html
Enter http://arduino.esp8266.com/stable/package_esp8266com_index.json into Additional Board Manager URLs field. You can add multiple URLs, separating them with commas. This will add support for the Wemos D1 Mini to Arduino IDE.
Open Boards Manager from Tools > **Board menu and install esp8266 Core platform version 2.5.2**
Select Board: "LOLIN(WEMOS) D1 R2 & mini"
Set Flash Size to 1M SPIFFS -- this project requires SPIFFS for saving and reading configuration settings.
Select the Port from the tools menu.

Closed 2021-12-11.

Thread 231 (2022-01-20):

Display issues

jimus888, 2022-01-20:
Hi,

Im having issues getting my screen to display correctly. Have attached some example pics and chip info.

For troubleshooting I have done the following:
- checked wiring
- checked esp8266 board library is 2.5.2
- checked flash size is 1M
- ran bin update to current version
- Tried rotating the output

I can occasionally see the bottom row scrolling, then other lights will randomly light up, then all lights go off

Any ideas what is causing my problems?

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

Qrome, 2022-01-20:
@jimus888 -- thank you for providing all the details.   From first glance with this type of issue I would say check the ESP8266 core version is 2.5.8 and the 1M SPIFF
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
It looks like you have covered all that.

What is the LED board you are using?  I wonder if it is a different control chip on the LED board.

jimus888, 2022-01-23:
Hi.

Just wanted to let you know I got it working :)

the code was fine. Thanks for your help

FYI The fix was to power the display from the 3v3 pin on my esp8266 board

Closed 2022-01-23.

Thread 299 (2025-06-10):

Weather Data or Parsing Error?

horsenot, 2025-06-10:
When my clock makes a call for Weather API using unchanged code, I get a 401 error despite my key being verified to work, and my sign will display news headlines, so I don't think it's a connectivity issue.  I was looking at the openweathermap 2.5 (free) API documentation, and group query needs to be changed to weather query to get a return, but when I do that, I get this from the serial monitor in the IDE:

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

It seems as if the structure of the data output of the newer free query doesn't line up with the output of the old query, so does this mean it's not parsing the JSON output from openweathermap or is it just not receiving any data whatsoever?  Do I need to upgrade to onecall 3.0, or are there some things I can change to make the 2.5 current weather API work?  Maybe I messed up the install? I know there are more weather error checks that should be getting triggered here, but it's not triggering them.  I have spent a few hours trying to fix it, and I think it's time to ask people that know more than I do.  I thought I had looked through all of the other issue threads, but nothing really stood out as being the same error, so, sorry in advance if that's not the case or if it's a simple issue and I just messed something up.  What's even more frustrating is that I'm not certain on narrowing down what the issue is because I'm on a v4.0 clone board (flashed as a clone), so that might be part of it, I have the timelib redefine warnings like Issue thread #272 has, but the display scrolls fine, shows the incorrect time, incorrect weather data, a custom message, and like I said earlier, it will display news headlines.  I am pretty much dead in the water right now, have done five or six fresh recompiles with the same exact results, and maybe a fresh perspective would be for the best.  Thanks.

Additional info:

Arduino IDE 2.3.6 on win10
Adafruit GFX Library 1.12.1 with Adafruit BusIO 1.17.1 dependency
json streaming parser by Daniel Eichhorn 1.0.5
Time by Michael Margolis 1.6.1
WiFiManager by tzapu 2.0.17
Max 72xx is installed but doesn't show under library manager

rob040, 2025-06-29:
That is all correct.  OpenWeatherMap has changed the API but kept the version the same.
Newly requested API keys do no longer have access
 to the GET /data/2.5/group?... , but must use the GET /data/2.5/weather?... request.
Also the returned json format has changed.

OLD OpenWeatherMap API keys are still working though.

My fork ( https://github.com/rob040/LEDmatrixClock ) has that resolved.

costascontis, 2025-06-29:
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

thnx mate this is awesome,so the bins at your fork are updated or do i have to compile by source?

rob040, 2025-06-29:
There are no pre-build binaries available yet. I still have some stuff on my todo list, then I'll create a release with binaries.

Feel free to compile and report your findings.

rob040, 2025-07-04:
I have created a release with binary, that solves this and other issues. See https://github.com/rob040/LEDmatrixClock/releases

anotherbob67, 2025-08-30:
rob040 - thanks for getting this going again. I need to restore the news and ocotoprint functions.

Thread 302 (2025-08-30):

Weather Data Error: HTTP/1.1 401 Unauthorized

pepperm2, 2025-08-30:
How can I fix this error please? started getting it a few dats ago.

nanomdq, 2025-08-30:
Same problem here, and the clock doesn't work either, it starts at 0.00

anotherbob67, 2025-08-30:
See issue #299 - see the github fork for rob040 - you'll loose everything but weather and the clock... but it will work again.

rob040, 2025-08-30:
Indeed, See also [New OpenWeather API](https://github.com/Qrome/marquee-scroller/issues/291#top) #291

Regarding the above "_you'll loose everything_" possibly refers to that News, Pi-Hole and OctoPrint are not included in this fork:
 https://github.com/rob040/LEDmatrixClock/releases

But you do get bank a lot of [Feature Enhancements](https://github.com/rob040/LEDmatrixClock#feature-enhancements)

heidepiek, 2025-08-31:
i am by no means a programmer, i like the LEDmatrixClock made by rob040. But i also like my old marquee scroller. I have alterd the OpenWeatherMapClient.cpp header file. And now my scroller is working as it did before i got the Weather Data Error: HTTP/1.1 401 Unauthorized.    Hope that others also have this luck if they use this header:

[OpenWeatherMapClient.zip](https://github.com/user-attachments/files/22066588/OpenWeatherMapClient.zip)

Greetz
Harke

pepperm2, 2025-08-31:
I have spent all night trying to do one of two things. Firstly I tried to upload the LEDmatricClock bin file to my 3.02 marque system, and it didnt work. Secondly I have been trying to compile the LEDmatrixClock code with the arduino IDE and I currently get the following error: Compilation error: expected unqualified-id before 'false'. I have all sorts of library errors that I have overcome with library installs, now I'm stuck on this error.

Has anyone any ideas? please...

wilsonjc, 2025-09-02:
The problem may lie with the new open weather limit, which restricts the number of requests to 1000 free per day, before they start charging your credit card $ 0.0015 USD per request.   Also, you may have to update your account to include your credit card to use even the free account.  The marquee scroller requests the weather every minute, so the cost to you would be $4.62us per week.    I see a few solutions to this problem.   First, we could stay with open weather and update the weather every 2 minutes or more, or change to another free weather provider like open-meteo.com.    Any ideas?

rob040, 2025-09-02:
> The problem may lie with the new open weather limit, which restricts the number of requests to 1000 free per day, before they start charging your credit card $ 0.0015 USD per request. Also, you may have to update your account to include your credit card to use even the free account. The marquee scroller requests the weather every minute, so the cost to you would be $4.62us per week. I see a few solutions to this problem. First, we could stay with open weather and update the weather every 2 minutes or more, or change to another free weather provider like open-meteo.com. Any ideas?

That is incorrect.

We use the [Free Access](https://openweathermap.org/price) API calls, which is totally free and does not require you to share any financial information, like credit card or so.

Only for the "[One Call API 3.0](https://openweathermap.org/api/one-call-3)", **which we do NOT use**, there is a "Pay as you call" subscription as described above.

I do not know exactly what happens if you have subscribed for some payment plan, but use only the Free Access API calls. I expect, as for every one, it is still free.

rob040, 2025-09-02:
> I altered the openweathermapclient.h And my clock is running good until now. News, weather and scrolling text with no hickups. Trye it please, and if it works. Please give a command back.

@heidepiek I don't know what you are tying to do here, but the file you posted is EXACTLY the same as current [OpenWeatherMapClient.h](https://github.com/Qrome/marquee-scroller/blob/master/marquee/OpenWeatherMapClient.h).
Besides that, the required change is not in the .h but in the .cpp file.

cryo, 2025-09-05:
Can we get a new build with https://api.openweathermap.org/data/3.0/onecall?lat=33.44&lon=-94.04&appid=[your_openweather_api_key]

rob040, 2025-09-06:
We will stick to the FREE ACCESS API of open weather map; the paid subscription is out of the question.

rob040, 2025-09-06:
I have to apologize here; upon the remark from cryo that I received in my notification I responded without realizing it was an issue on Qrome and not on my own repo, so I changed my reply in more general terms, but have to realize I can't talk for Qrome.

For project [Qrome/marquee-scroller](https://github.com/Qrome/marquee-scroller/) it does not receive the required OpenWeatherMap API update in neither form.

For the forked project [rob040/LEDmatrixClock](https://github.com/rob040/LEDmatrixClock), it is now fully functional and it will stick to the free access OWM API, as per my [comment above](https://github.com/Qrome/marquee-scroller/issues/302#issuecomment-3261531734).

If you need Octoprint you have the following options:
1. create and maintain your own fork; you already made a pretty good start with last [OpenWeatherMapClient.zip](https://github.com/user-attachments/files/22099702/OpenWeatherMapClient.zip)
2. use the print monitor with OLED display
3. use the Octopint (OctoPi) web interface
4. use an MQTT gateway to send messages to the LED matrix display

In my opinion, the Octoprint implementation on marquee scroller is just too limited and the used 'progress bar' is not intuitive. The LED matrix display isn't suited for this usage; the OLED display is much better suited, though I have no experience with that, as I use the OctoPi webinterface. Besides, an 3D printer is best monitored with your own presence.

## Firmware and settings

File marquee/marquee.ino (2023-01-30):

/** The MIT License (MIT)

  Copyright (c) 2018 David Payne

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
  THE SOFTWARE IS PROVIDED "AS IS", WITHOUT WARRANTY OF ANY KIND, EXPRESS OR
  IMPLIED, INCLUDING BUT NOT LIMITED TO THE WARRANTIES OF MERCHANTABILITY,
  FITNESS FOR A PARTICULAR PURPOSE AND NONINFRINGEMENT. IN NO EVENT SHALL THE
  AUTHORS OR COPYRIGHT HOLDERS BE LIABLE FOR ANY CLAIM, DAMAGES OR OTHER
  LIABILITY, WHETHER IN AN ACTION OF CONTRACT, TORT OR OTHERWISE, ARISING FROM,
  OUT OF OR IN CONNECTION WITH THE SOFTWARE OR THE USE OR OTHER DEALINGS IN THE
  SOFTWARE.
*/

/**********************************************
  Edit Settings.h for personalization
***********************************************/

#include "Settings.h"

#define VERSION "3.03"

#define HOSTNAME "CLOCK-"
#define CONFIG "/conf.txt"
#define BUZZER_PIN  D2

/* Useful Constants */
#define SECS_PER_MIN  (60UL)
#define SECS_PER_HOUR (3600UL)
#define SECS_PER_DAY  (SECS_PER_HOUR * 24L)

/* Useful Macros for getting elapsed time */
#define numberOfSeconds(_time_) (_time_ % SECS_PER_MIN)
#define numberOfMinutes(_time_) ((_time_ / SECS_PER_MIN) % SECS_PER_MIN)
#define numberOfHours(_time_) (( _time_% SECS_PER_DAY) / SECS_PER_HOUR)
#define elapsedDays(_time_) ( _time_ / SECS_PER_DAY)

//declairing prototypes
void configModeCallback (WiFiManager *myWiFiManager);
int8_t getWifiQuality();

// LED Settings
const int offset = 1;
int refresh = 0;
String message = "hello";
int spacer = 1;  // dots between letters
int width = 5 + spacer; // The font width is 5 pixels + spacer
Max72xxPanel matrix = Max72xxPanel(pinCS, numberOfHorizontalDisplays, numberOfVerticalDisplays);
String Wide_Clock_Style = "1";  //1="hh:mm Temp", 2="hh:mm:ss", 3="hh:mm"
float UtcOffset;  //time zone offsets that correspond with the CityID above (offset from GMT)

// Time
TimeDB TimeDB("");
String lastMinute = "xx";
int displayRefreshCount = 1;
long lastEpoch = 0;
long firstEpoch = 0;
long displayOffEpoch = 0;
boolean displayOn = true;

// News Client
NewsApiClient newsClient(NEWS_API_KEY, NEWS_SOURCE);
int newsIndex = 0;

// Weather Client
OpenWeatherMapClient weatherClient(APIKEY, CityIDs, 1, IS_METRIC);
// (some) Default Weather Settings
boolean SHOW_DATE = false;
boolean SHOW_CITY = true;
boolean SHOW_CONDITION = true;
boolean SHOW_HUMIDITY = true;
boolean SHOW_WIND = true;
boolean SHOW_WINDDIR = true;
boolean SHOW_PRESSURE = false;
boolean SHOW_HIGHLOW = true;

// OctoPrint Client
OctoPrintClient printerClient(OctoPrintApiKey, OctoPrintServer, OctoPrintPort, OctoAuthUser, OctoAuthPass);
int printerCount = 0;

// Pi-hole Client
PiHoleClient piholeClient;

ESP8266WebServer server(WEBSERVER_PORT);
ESP8266HTTPUpdateServer serverUpdater;

static const char WEB_ACTIONS1[] PROGMEM = "<a class='w3-bar-item w3-button' href='/'><i class='fas fa-home'></i> Home</a>"
                        "<a class='w3-bar-item w3-button' href='/configure'><i class='fas fa-cog'></i> Configure</a>"
                        "<a class='w3-bar-item w3-button' href='/configurenews'><i class='far fa-newspaper'></i> News</a>"
                        "<a class='w3-bar-item w3-button' href='/configureoctoprint'><i class='fas fa-cube'></i> OctoPrint</a>";

static const char WEB_ACTIONS2[] PROGMEM = "<a class='w3-bar-item w3-button' href='/configurepihole'><i class='fas fa-network-wired'></i> Pi-hole</a>"
                        "<a class='w3-bar-item w3-button' href='/pull'><i class='fas fa-cloud-download-alt'></i> Refresh Data</a>"
                        "<a class='w3-bar-item w3-button' href='/display'>";

static const char WEB_ACTION3[] PROGMEM = "</a><a class='w3-bar-item w3-button' href='/systemreset' onclick='return confirm(\"Do you want to reset to default weather settings?\")'><i class='fas fa-undo'></i> Reset Settings</a>"
                       "<a class='w3-bar-item w3-button' href='/forgetwifi' onclick='return confirm(\"Do you want to forget to WiFi connection?\")'><i class='fas fa-wifi'></i> Forget WiFi</a>"
                       "<a class='w3-bar-item w3-button' href='/update'><i class='fas fa-wrench'></i> Firmware Update</a>"
                       "<a class='w3-bar-item w3-button' href='https://github.com/Qrome/marquee-scroller' target='_blank'><i class='fas fa-question-circle'></i> About</a>";

static const char CHANGE_FORM1[] PROGMEM = "<form class='w3-container' action='/locations' method='get'><h2>Configure:</h2>"
                      "<label>TimeZone DB API Key (get from <a href='https://timezonedb.com/register' target='_BLANK'>here</a>)</label>"
                      "<input class='w3-input w3-border w3-margin-bottom' type='text' name='TimeZoneDB' value='%TIMEDBKEY%' maxlength='60'>"
                      "<label>OpenWeatherMap API Key (get from <a href='https://openweathermap.org/' target='_BLANK'>here</a>)</label>"
                      "<input class='w3-input w3-border w3-margin-bottom' type='text' name='openWeatherMapApiKey' value='%WEATHERKEY%' maxlength='70'>"
                      "<p><label>%CITYNAME1% (<a href='http://openweathermap.org/find' target='_BLANK'><i class='fas fa-search'></i> Search for City ID</a>)</label>"
                      "<input class='w3-input w3-border w3-margin-bottom' type='text' name='city1' value='%CITY1%' onkeypress='return isNumberKey(event)'></p>"
                      "<p><input name='metric' class='w3-check w3-margin-top' type='checkbox' %CHECKED%> Use Metric (Celsius)</p>"
                      "<p><input name='showdate' class='w3-check w3-margin-top' type='checkbox' %DATE_CHECKED%> Display Date</p>"
                      "<p><input name='showcity' class='w3-check w3-margin-top' type='checkbox' %CITY_CHECKED%> Display City Name</p>"
                      "<p><input name='showhighlow' class='w3-check w3-margin-top' type='checkbox' %HIGHLOW_CHECKED%> Display Current High/Low Temperatures</p>"
                      "<p><input name='showcondition' class='w3-check w3-margin-top' type='checkbox' %CONDITION_CHECKED%> Display Weather Condition</p>"
                      "<p><input name='showhumidity' class='w3-check w3-margin-top' type='checkbox' %HUMIDITY_CHECKED%> Display Humidity</p>"
                      "<p><input name='showwind' class='w3-check w3-margin-top' type='checkbox' %WIND_CHECKED%> Display Wind</p>"
                      "<p><input name='showpressure' class='w3-check w3-margin-top' type='checkbox' %PRESSURE_CHECKED%> Display Barometric Pressure</p>"
                      "<p><input name='is24hour' class='w3-check w3-margin-top' type='checkbox' %IS_24HOUR_CHECKED%> Use 24 Hour Clock (military time)</p>";

static const char CHANGE_FORM2[] PROGMEM = "<p><input name='isPM' class='w3-check w3-margin-top' type='checkbox' %IS_PM_CHECKED%> Show PM indicator (only 12h format)</p>"
                      "<p><input name='flashseconds' class='w3-check w3-margin-top' type='checkbox' %FLASHSECONDS%> Flash : in the time</p>"
                      "<p><label>Marquee Message (up to 60 chars)</label><input class='w3-input w3-border w3-margin-bottom' type='text' name='marqueeMsg' value='%MSG%' maxlength='60'></p>"
                      "<p><label>Start Time </label><input name='startTime' type='time' value='%STARTTIME%'></p>"
                      "<p><label>End Time </label><input name='endTime' type='time' value='%ENDTIME%'></p>"
                      "<p>Display Brightness <input class='w3-border w3-margin-bottom' name='ledintensity' type='number' min='0' max='15' value='%INTENSITYOPTIONS%'></p>"
                      "<p>Display Scroll Speed <select class='w3-option w3-padding' name='scrollspeed'>%SCROLLOPTIONS%</select></p>"
                      "<p>Minutes Between Refresh Data <select class='w3-option w3-padding' name='refresh'>%OPTIONS%</select></p>"
                      "<p>Minutes Between Scrolling Data <input class='w3-border w3-margin-bottom' name='refreshDisplay' type='number' min='1' max='10' value='%REFRESH_DISPLAY%'></p>"
                      "<p>Theme Color <select class='w3-option w3-padding' name='theme'>%THEME_OPTIONS%</select></p>";

static const char CHANGE_FORM3[] PROGMEM = "<hr><p><input name='isBasicAuth' class='w3-check w3-margin-top' type='checkbox' %IS_BASICAUTH_CHECKED%> Use Security Credentials for Configuration Changes</p>"
                      "<p><label>Marquee User ID (for this web interface)</label><input class='w3-input w3-border w3-margin-bottom' type='text' name='userid' value='%USERID%' maxlength='20'></p>"
                      "<p><label>Marquee Password </label><input class='w3-input w3-border w3-margin-bottom' type='password' name='stationpassword' value='%STATIONPASSWORD%'></p>"
                      "<p><button class='w3-button w3-block w3-green w3-section w3-padding' type='submit'>Save</button></p></form>"
                      "<script>function isNumberKey(e){var h=e.which?e.which:event.keyCode;return!(h>31&&(h<48||h>57))}</script>";

static const char WIDECLOCK_FORM[] PROGMEM = "<form class='w3-container' action='/savewideclock' method='get'><h2>Wide Clock Configuration:</h2>"
                          "<p>Wide Clock Display Format <select class='w3-option w3-padding' name='wideclockformat'>%WIDECLOCKOPTIONS%</select></p>"
                          "<button class='w3-button w3-block w3-grey w3-section w3-padding' type='submit'>Save</button></form>";

static const char PIHOLE_FORM[] PROGMEM = "<form class='w3-container' action='/savepihole' method='get'><h2>Pi-hole Configuration:</h2>"
                        "<p><input name='displaypihole' class='w3-check w3-margin-top' type='checkbox' %PIHOLECHECKED%> Show Pi-hole Statistics</p>"
                        "<label>Pi-hole Address (do not include http://)</label><input class='w3-input w3-border w3-margin-bottom' type='text' name='piholeAddress' id='piholeAddress' value='%PIHOLEADDRESS%' maxlength='60'>"
                        "<label>Pi-hole Port</label><input class='w3-input w3-border w3-margin-bottom' type='text' name='piholePort' id='piholePort' value='%PIHOLEPORT%' maxlength='5'  onkeypress='return isNumberKey(event)'>"
                        "<label>Pi-hole API Token (from Pi-hole &rarr; Settings &rarr; API/Web interface)</label>"
                        "<input class='w3-input w3-border w3-margin-bottom' type='text' name='piApiToken' id='piApiToken' value='%PIAPITOKEN%' maxlength='65'>"
                        "<input type='button' value='Test Connection and JSON Response' onclick='testPiHole()'><p id='PiHoleTest'></p>"
                        "<button class='w3-button w3-block w3-green w3-section w3-padding' type='submit'>Save</button></form>"
                        "<script>function isNumberKey(e){var h=e.which?e.which:event.keyCode;return!(h>31&&(h<48||h>57))}</script>";

static const char PIHOLE_TEST[] PROGMEM = "<script>function testPiHole(){var e=document.getElementById(\"PiHoleTest\"),t=document.getElementById(\"piholeAddress\").value,"
                       "n=document.getElementById(\"piholePort\").value,api=document.getElementById(\"piApiToken\").value;;"
                       "if(e.innerHTML=\"\",\"\"==t||\"\"==n)return e.innerHTML=\"* Address and Port are required\","
                       "void(e.style.background=\"\");var r=\"http://\"+t+\":\"+n;r+=\"/admin/api.php?summary=3&auth=\"+api,window.open(r,\"_blank\").focus()}</script>";

static const char NEWS_FORM1[] PROGMEM =   "<form class='w3-container' action='/savenews' method='get'><h2>News Configuration:</h2>"
                        "<p><input name='displaynews' class='w3-check w3-margin-top' type='checkbox' %NEWSCHECKED%> Display News Headlines</p>"
                        "<label>News API Key (get from <a href='https://newsapi.org/' target='_BLANK'>here</a>)</label>"
                        "<input class='w3-input w3-border w3-margin-bottom' type='text' name='newsApiKey' value='%NEWSKEY%' maxlength='60'>"
                        "<p>Select News Source <select class='w3-option w3-padding' name='newssource' id='newssource'></select></p>"
                        "<script>var s='%NEWSSOURCE%';var tt;var xmlhttp=new XMLHttpRequest();xmlhttp.open('GET','https://raw.githubusercontent.com/Qrome/marquee-scroller/master/sources.json',!0);"
                        "xmlhttp.onreadystatechange=function(){if(xmlhttp.readyState==4){if(xmlhttp.status==200){var obj=JSON.parse(xmlhttp.responseText);"
                        "obj.sources.forEach(t)}}};xmlhttp.send();function t(it){if(it!=null){if(s==it.id){se=' selected'}else{se=''}tt+='<option'+se+'>'+it.id+'</option>';"
                        "document.getElementById('newssource').innerHTML=tt}}</script>"
                        "<button class='w3-button w3-block w3-grey w3-section w3-padding' type='submit'>Save</button></form>";
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
void loop() {
  //Get some Weather Data to serve
  if ((getMinutesFromLastRefresh() >= minutesBetweenDataRefresh) || lastEpoch == 0) {
    getWeatherData();
  }
  checkDisplay(); // this will see if we need to turn it on or off for night mode.

  if (lastMinute != TimeDB.zeroPad(minute())) {
    lastMinute = TimeDB.zeroPad(minute());

    if (weatherClient.getError() != "") {
      scrollMessage(weatherClient.getError());
      return;
    }

    if (displayOn) {
      matrix.shutdown(false);
    }
    matrix.fillScreen(LOW); // show black
    if (OCTOPRINT_ENABLED) {
      if (displayOn && ((printerClient.isOperational() || printerClient.isPrinting()) || printerCount == 0)) {
        // This should only get called if the printer is actually running or if it has been 2 minutes since last check
        printerClient.getPrinterJobResults();
      }
      printerCount += 1;
      if (printerCount > 2) {
        printerCount = 0;
      }
    }

    displayRefreshCount --;
    // Check to see if we need to Scroll some Data
    if (displayRefreshCount <= 0) {
      displayRefreshCount = minutesBetweenScrolling;
      String temperature = weatherClient.getTempRounded(0);
      String description = weatherClient.getDescription(0);
      description.toUpperCase();
      String msg;
      msg += " ";

      if (SHOW_DATE) {
        msg += TimeDB.getDayName() + ", ";
        msg += TimeDB.getMonthName() + " " + day() + "  ";
      }
      if (SHOW_CITY) {
        msg += weatherClient.getCity(0) + "  ";
      }
      msg += temperature + getTempSymbol() + "  ";

      //show high/low temperature
      if (SHOW_HIGHLOW) {
        msg += "High/Low:" + weatherClient.getHigh(0) + "/" + weatherClient.getLow(0) + " " + getTempSymbol() + "  ";
      }
      
      if (SHOW_CONDITION) {
        msg += description + "  ";
      }
      if (SHOW_HUMIDITY) {
        msg += "Humidity:" + weatherClient.getHumidityRounded(0) + "%  ";
      }
      if (SHOW_WIND) {
        msg += "Wind: " + weatherClient.getDirectionText(0) + " @ " + weatherClient.getWindRounded(0) + " " + getSpeedSymbol() + "  ";
      }
      //line to show barometric pressure
      if (SHOW_PRESSURE) {
        msg += "Pressure:" + weatherClient.getPressure(0) + getPressureSymbol() + "  ";
      }
     
      msg += marqueeMessage + " ";
      
      if (NEWS_ENABLED) {
        msg += "  " + NEWS_SOURCE + ": " + newsClient.getTitle(newsIndex) + "  ";
        newsIndex += 1;
        if (newsIndex > 9) {
          newsIndex = 0;
        }
      }
      if (OCTOPRINT_ENABLED && printerClient.isPrinting()) {
        msg += "  " + printerClient.getFileName() + " ";
        msg += "(" + printerClient.getProgressCompletion() + "%)  ";
      }
      if (USE_PIHOLE) {
        piholeClient.getPiHoleData(PiHoleServer, PiHolePort, PiHoleApiKey);
        piholeClient.getGraphData(PiHoleServer, PiHolePort, PiHoleApiKey);
        if (piholeClient.getPiHoleStatus() != "") {
          msg += "    Pi-hole (" + piholeClient.getPiHoleStatus() + "): " + piholeClient.getAdsPercentageToday() + "% "; 
        }
      }

      scrollMessage(msg);
      drawPiholeGraph();
    }
  }

  String currentTime = hourMinutes(false);

  if (numberOfHorizontalDisplays >= 8) {
    if (Wide_Clock_Style == "1") {
      // On Wide Display -- show the current temperature as well
      String currentTemp = weatherClient.getTempRounded(0);
      currentTime += " " + currentTemp + getTempSymbol();
    }
    if (Wide_Clock_Style == "2") {
      currentTime = currentTime + secondsIndicator(false) + TimeDB.zeroPad(second());
      matrix.fillScreen(LOW); // show black
    }
    if (Wide_Clock_Style == "3") {
      // No change this is normal clock display
    }
  }
  matrix.fillScreen(LOW);
  centerPrint(currentTime, true);

  if (WEBSERVER_ENABLED) {
    server.handleClient();
  }
  if (ENABLE_OTA) {
    ArduinoOTA.handle();
  }
}

String zeroPad(int value) {
  String rtnValue = String(value);
  if (value < 10) {
    rtnValue = "0" + rtnValue;
  }
  return rtnValue;
}

String hourMinutes(boolean isRefresh) {
  if (IS_24HOUR) {
    return String(hour()) + secondsIndicator(isRefresh) + TimeDB.zeroPad(minute());
  } else {
    return String(hourFormat12()) + secondsIndicator(isRefresh) + TimeDB.zeroPad(minute());
  }
}

String secondsIndicator(boolean isRefresh) {
  String rtnValue = ":";
  if (isRefresh == false && (flashOnSeconds && (second() % 2) == 0)) {
    rtnValue = " ";
  }
  return rtnValue;
}

boolean athentication() {
  if (IS_BASIC_AUTH) {
    return server.authenticate(www_username, www_password);
  }
  return true; // Authentication not required
}

void handlePull() {
  getWeatherData(); // this will force a data pull for new weather
  displayWeatherData();
}

void handleSaveWideClock() {
  if (!athentication()) {
    return server.requestAuthentication();
  }
  if (numberOfHorizontalDisplays >= 8) {
    Wide_Clock_Style = server.arg("wideclockformat");
    writeCityIds();
    matrix.fillScreen(LOW); // show black
  }
  redirectHome();
}

void handleSaveNews() {
  if (!athentication()) {
    return server.requestAuthentication();
  }
  NEWS_ENABLED = server.hasArg("displaynews");
  NEWS_API_KEY = server.arg("newsApiKey");
  NEWS_SOURCE = server.arg("newssource");
  matrix.fillScreen(LOW); // show black
  writeCityIds();
  newsClient.updateNews();
  redirectHome();
}

void handleSaveOctoprint() {
  if (!athentication()) {
    return server.requestAuthentication();
  }
  OCTOPRINT_ENABLED = server.hasArg("displayoctoprint");
  OCTOPRINT_PROGRESS = server.hasArg("octoprintprogress");
  OctoPrintApiKey = server.arg("octoPrintApiKey");
  OctoPrintServer = server.arg("octoPrintAddress");
  OctoPrintPort = server.arg("octoPrintPort").toInt();
  OctoAuthUser = server.arg("octoUser");
  OctoAuthPass = server.arg("octoPass");
  matrix.fillScreen(LOW); // show black
  writeCityIds();
  if (OCTOPRINT_ENABLED) {
    printerClient.getPrinterJobResults();
  }
  redirectHome();
}

void handleSavePihole() {
  if (!athentication()) {
    return server.requestAuthentication();
  }
  USE_PIHOLE = server.hasArg("displaypihole");
  PiHoleServer = server.arg("piholeAddress");
  PiHolePort = server.arg("piholePort").toInt();
  PiHoleApiKey = server.arg("piApiToken");
  Serial.println("PiHoleApiKey from save: " + PiHoleApiKey);
  writeCityIds();
  if (USE_PIHOLE) {
    piholeClient.getPiHoleData(PiHoleServer, PiHolePort, PiHoleApiKey);
    piholeClient.getGraphData(PiHoleServer, PiHolePort, PiHoleApiKey);
  }
  redirectHome();
}

void handleLocations() {
  if (!athentication()) {
    return server.requestAuthentication();
  }
  TIMEDBKEY = server.arg("TimeZoneDB");
  APIKEY = server.arg("openWeatherMapApiKey");
  CityIDs[0] = server.arg("city1").toInt();
  flashOnSeconds = server.hasArg("flashseconds");
  IS_24HOUR = server.hasArg("is24hour");
  IS_PM = server.hasArg("isPM");
  SHOW_DATE = server.hasArg("showdate");
  SHOW_CITY = server.hasArg("showcity");
  SHOW_CONDITION = server.hasArg("showcondition");
  SHOW_HUMIDITY = server.hasArg("showhumidity");
  SHOW_WIND = server.hasArg("showwind");
  SHOW_PRESSURE = server.hasArg("showpressure");
  SHOW_HIGHLOW = server.hasArg("showhighlow");
  IS_METRIC = server.hasArg("metric");
  marqueeMessage = decodeHtmlString(server.arg("marqueeMsg"));
  timeDisplayTurnsOn = decodeHtmlString(server.arg("startTime"));
  timeDisplayTurnsOff = decodeHtmlString(server.arg("endTime"));
  displayIntensity = server.arg("ledintensity").toInt();
  minutesBetweenDataRefresh = server.arg("refresh").toInt();
  themeColor = server.arg("theme");
  minutesBetweenScrolling = server.arg("refreshDisplay").toInt();
  displayScrollSpeed = server.arg("scrollspeed").toInt();
  IS_BASIC_AUTH = server.hasArg("isBasicAuth");
  String temp = server.arg("userid");
  temp.toCharArray(www_username, sizeof(temp));
  temp = server.arg("stationpassword");
  temp.toCharArray(www_password, sizeof(temp));
  weatherClient.setMetric(IS_METRIC);
  matrix.fillScreen(LOW); // show black
  writeCityIds();
  getWeatherData(); // this will force a data pull for new weather
  redirectHome();
}

void handleSystemReset() {
  if (!athentication()) {
    return server.requestAuthentication();
  }
  Serial.println("Reset System Configuration");
  if (SPIFFS.remove(CONFIG)) {
    redirectHome();
    ESP.restart();
  }
}

void handleForgetWifi() {
  if (!athentication()) {
    return server.requestAuthentication();
  }
  //WiFiManager
  //Local intialization. Once its business is done, there is no need to keep it around
  redirectHome();
  WiFiManager wifiManager;
  wifiManager.resetSettings();
  ESP.restart();
}
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

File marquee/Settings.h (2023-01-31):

/** The MIT License (MIT)

Copyright (c) 2018 David Payne

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
THE SOFTWARE IS PROVIDED "AS IS", WITHOUT WARRANTY OF ANY KIND, EXPRESS OR
IMPLIED, INCLUDING BUT NOT LIMITED TO THE WARRANTIES OF MERCHANTABILITY,
FITNESS FOR A PARTICULAR PURPOSE AND NONINFRINGEMENT. IN NO EVENT SHALL THE
AUTHORS OR COPYRIGHT HOLDERS BE LIABLE FOR ANY CLAIM, DAMAGES OR OTHER
LIABILITY, WHETHER IN AN ACTION OF CONTRACT, TORT OR OTHERWISE, ARISING FROM,
OUT OF OR IN CONNECTION WITH THE SOFTWARE OR THE USE OR OTHER DEALINGS IN THE
SOFTWARE.
*/

/******************************************************************************
 * This is designed for the Wemos D1 ESP8266
 * Wemos D1 Mini:  https://amzn.to/2qLyKJd
 * MAX7219 Dot Matrix Module 4-in-1 Display For Arduino
 * Matrix Display:  https://amzn.to/2HtnQlD
 ******************************************************************************/
/******************************************************************************
 * NOTE: The settings here are the default settings for the first loading.  
 * After loading you will manage changes to the settings via the Web Interface.  
 * If you want to change settings again in the settings.h, you will need to 
 * erase the file system on the Wemos or use the “Reset Settings” option in 
 * the Web Interface.
 ******************************************************************************/
 
#include <ESP8266WiFi.h>
#include <ESP8266WebServer.h>
#include <ESP8266HTTPUpdateServer.h>
#include <WiFiManager.h> // --> https://github.com/tzapu/WiFiManager
#include <ESP8266mDNS.h>
#include <ArduinoOTA.h>
#include "FS.h"
#include <SPI.h>
#include <Adafruit_GFX.h> // --> https://github.com/adafruit/Adafruit-GFX-Library
#include <Max72xxPanel.h> // --> https://github.com/markruys/arduino-Max72xxPanel
#include <pgmspace.h>
#include "OpenWeatherMapClient.h"
#include "TimeDB.h"
#include "NewsApiClient.h" 
#include "OctoPrintClient.h"
#include "PiHoleClient.h"

//******************************
// Start Settings
//******************************

String TIMEDBKEY = ""; // Your API Key from https://timezonedb.com/register
String APIKEY = ""; // Your API Key from http://openweathermap.org/
// Default City Location (use http://openweathermap.org/find to find city ID)
int CityIDs[] = { 5304391 }; //Only USE ONE for weather marquee
String marqueeMessage = "";
boolean IS_METRIC = false; // false = Imperial and true = Metric
boolean IS_24HOUR = false; // 23:00 millitary 24 hour clock
boolean IS_PM = true; // Show PM indicator on Clock when in AM/PM mode
const int WEBSERVER_PORT = 80; // The port you can access this device on over HTTP
const boolean WEBSERVER_ENABLED = true;  // Device will provide a web interface via http://[ip]:[port]/
boolean IS_BASIC_AUTH = false;  // Use Basic Authorization for Configuration security on Web Interface
char* www_username = "admin";  // User account for the Web Interface
char* www_password = "password";  // Password for the Web Interface
int minutesBetweenDataRefresh = 15;  // Time in minutes between data refresh (default 15 minutes)
int minutesBetweenScrolling = 1; // Time in minutes between scrolling data (default 1 minutes and max is 10)
int displayScrollSpeed = 25; // In milliseconds -- Configurable by the web UI (slow = 35, normal = 25, fast = 15, very fast = 5)
boolean flashOnSeconds = true; // when true the : character in the time will flash on and off as a seconds indicator

boolean NEWS_ENABLED = true;
String NEWS_API_KEY = ""; // Get your News API Key from https://newsapi.org
String NEWS_SOURCE = "reuters";  // https://newsapi.org/sources to get full list of news sources available

// Display Settings
// CLK -> D5 (SCK)  
// CS  -> D6 
// DIN -> D7 (MOSI)
const int pinCS = D6; // Attach CS to this pin, DIN to MOSI and CLK to SCK (cf http://arduino.cc/en/Reference/SPI )
int displayIntensity = 1;  //(This can be set from 0 - 15)
const int numberOfHorizontalDisplays = 4; // default 4 for standard 4 x 1 display Max size of 16
const int numberOfVerticalDisplays = 1; // default 1 for a single row height
/* set ledRotation for LED Display panels (3 is default)
0: no rotation
1: 90 degrees clockwise
2: 180 degrees
3: 90 degrees counter clockwise (default)
*/
int ledRotation = 3;

String timeDisplayTurnsOn = "06:30";  // 24 Hour Format HH:MM -- Leave blank for always on. (ie 05:30)
String timeDisplayTurnsOff = "23:00"; // 24 Hour Format HH:MM -- Leave blank for always on. Both must be set to work.
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

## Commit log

2018-04-23 Qrome - updated spelling issue.
    [marquee.ino]
2018-04-28 Qrome - fixed Octoprint issue
    [OctoPrintClient.cpp, marquee.ino]
2018-04-29 Qrome - updated optional Basic Auth and Error Handling for bad API Key
    [OpenWeatherMapClient.cpp, Settings.h, marquee.ino]
2018-05-02 Qrome - fixed news to only 10 stories to rotate through
    [marquee.ino]
2018-05-12 Qrome - fixed partial loading issue on configure page
    [marquee.ino]
2018-05-16 Added wire diagram
2018-05-16 Updated with wire diagram
2018-06-01 Qrome - updated OctoPrint Error Messages
    [OctoPrintClient.cpp, marquee.ino]
2018-06-05 Fixed a bug where News is skipped
    [marquee.ino]
2018-06-11 fix: Allow for chaining multiple displays
    [Settings.h, marquee.ino]
2018-06-16 Qrome - added API Keys to Web Interface and fixed Exception(28)
    [NewsApiClient.cpp, OpenWeatherMapClient.cpp, Settings.h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]
2018-07-03 Qrome - updated to show temperature when 8 wide on the LED
2018-08-07 Qrome - fixed some HTML form fields
    [marquee.ino]
2018-08-15 Qrome - removed loop on weather parsing error
    [OpenWeatherMapClient.cpp, marquee.ino]
2018-08-21 Qrome - updated spelling issues
    [marquee.ino]
2018-11-10 Adding support for the OTA updater web interface. It allows you to navigate to http://x.x.x.x/update to push .bin files to the device. http://esp8266.github.io/Arduino/versions/2.0.0/doc/ota_updates/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
2018-11-13 Fixed the default number of LED panels
    Put it back to 4 instead of 8
    [Settings.h]
2018-11-23 Qrome - updated indicator LED during loading and fixed flashing on seconds in wide mode
    [Settings.h, marquee.ino]
2018-12-15 Qrome - removed advice slip -- no longer working as it requires https
    [Settings.h, marquee.ino]
2018-12-17 Updated to default 4 led panels
2019-01-10 Qrome - added to ledRotation as a value to Settings.h
2019-01-20 Qrome - updated to allow for LED rotation value in Settings.h
2019-02-19 Qrome - updated to use ArduinoJson as a local library
2019-03-15 Qrome - changed centerPrint to remove flicker on PM ind and 3d print status line
2019-03-15 Qrome - fixed the last digit flicker and added some character cleaning
    [NewsApiClient.cpp, Settings.h, marquee.ino]
2019-03-15 Qrome - fixed the progress indicator to go to the top
    [Settings.h, marquee.ino]
2019-03-15 Qrome - changed printer on check from 5 minutes to 2
2019-03-20 Qrome - added 70 limit to weather key and 0 value on led intensity
2019-03-23 adding check to hopefully prevent time reverting to 12:00 on failed time update
    [OpenWeatherMapClient.cpp, marquee.ino]
2019-04-24 Qrome - added pi-hole class -- need to impliment
2019-04-24 Qrome - added Graphing Data and Web UI for pi-hole
2019-04-24 Qrome - added some pi-hole checking
2019-04-27 Qrome - fix to Pi-hole graph - bug when not enough data
    [PiHoleClient.cpp, marquee.ino]
2019-05-05 Updated files to implement speed & pressure
    Implemented wind speed and barometric pressure display.
2019-05-06 add additional weather features
    Support added for wind direction, barometric pressure, and daily high/low temperatures.
2019-05-29 Qrome - fix for ESP8266 Core 2.5.2 - access PROGMEM
    [marquee.ino]
2022-03-29 Added error messages for blank api keys and octoprint details
    [NewsApiClient.cpp, OpenWeatherMapClient.cpp, marquee.ino]
2022-03-30 updated bug fix for wide clock
    [marquee.ino]
2022-05-10 fixed bug on 24 our view with invalid character
    [marquee.ino]
2023-01-30 Updated to include the Pi-Hole API key to fix graghing
    [PiHoleClient.cpp, Settings.h, marquee.ino]
2023-01-30 Fixed graph data for pi-hole
    [PiHoleClient.cpp, Settings.h]
